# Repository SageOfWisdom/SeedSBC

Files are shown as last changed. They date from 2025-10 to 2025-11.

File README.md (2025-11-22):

# SeedSBC

## ICE40HX8K FPGA development board.
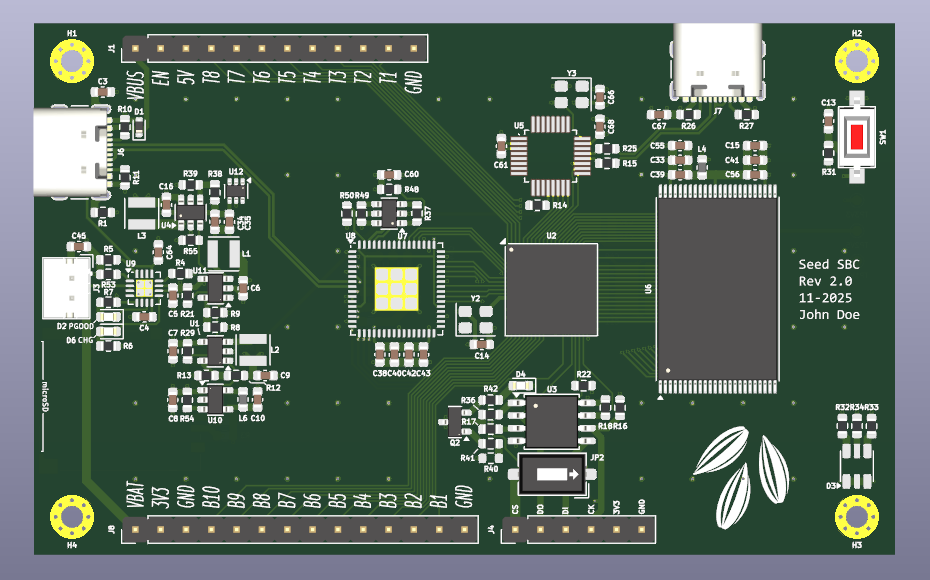
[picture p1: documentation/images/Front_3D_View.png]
Front Photo


## Latest Revision: 
* [SeedSBC rev2.0](hardware/rev2.0/)

Previous Revisions:
* [SeedSBC rev1.1](hardware/rev1.1/)
* [SeedSBC rev1.0](hardware/rev1.0/)

---

## What is it?
This is an Open Source Hardware single board computer and development board implementing the Lattice ICE40 FPGA. The board features regular I/O breakout pins, an SRAM unit, and a microSD MMC connector. The footprint is reminiscent of other "Altoids Tin" format SBCs.

## Hardware Overview
* Lattice ICE40HX8K FPGA in 121-Ball caBGA package

    * 7,680 - Logic Cells (LUT + Flip-Flop)
    * 32 - RAM4K Memory Blocks
    * 128k - RAM4K RAM bits
    * 2 - PLLs
    * 106 - Programmable I/O Pins
    * 13 - Differential Input Pairs
* SRAM Memory
    * 
* USB-C connection
    * 
* Non-Volatile Memory
    * asdf 
        * asdf
    * MicroSD socket
        * 4bit SD interface (CK, CMD, DAT0-3)
* Power supply
    * Battery charger (100mA), with LED charge indicators
    * Li-Ion battery connector
* 48MHz onboard oscillator
* Accessible 0.1" 2-wire SPI NVM programming breakout
* User I/O
    * 1x Button 
    * 1x RGB LED
    * 18x I/O on 0.1" headers
* Board Format
    * Dimensions: 86.36mm x 53.34mm (3.4" x 2.1")
    * 4x 2.2mm plated mounting holes
---

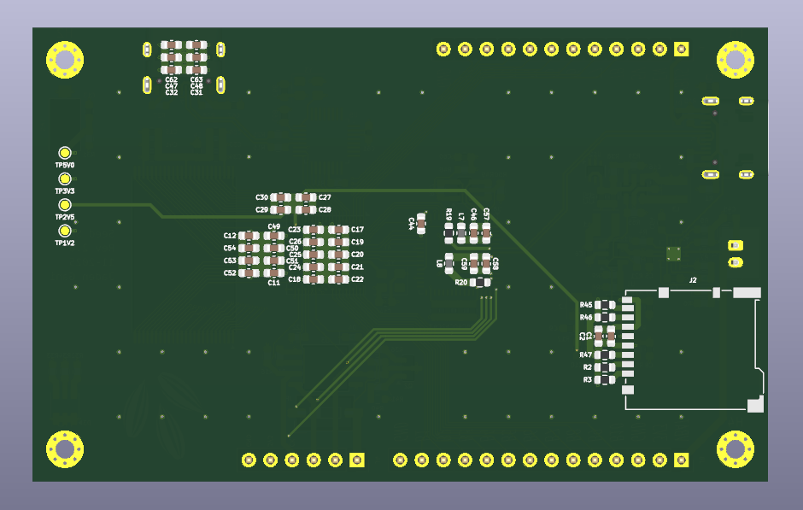
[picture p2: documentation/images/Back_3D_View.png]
Back Photo


## Example code
Example code for Verilog, And RiscV AVR can be found here:

* [ToDo]()

## Licence

 * None

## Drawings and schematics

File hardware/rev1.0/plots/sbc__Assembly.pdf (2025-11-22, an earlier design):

1 | 2 | 3 | 4 | 5 | 6

A

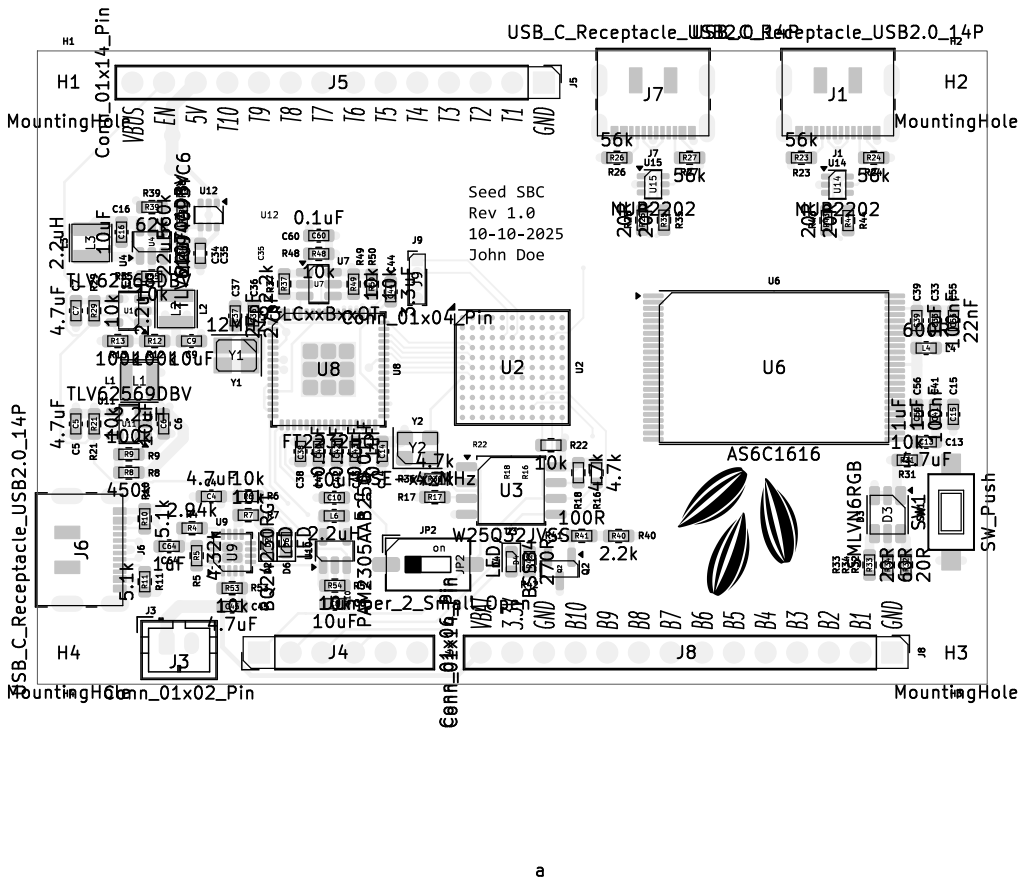
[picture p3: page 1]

Id: /1 Title: File: sbc.kicad_pcb Sheet: Black And White TOP

1 | 2 | 3 | 4 | 5 | 6

A

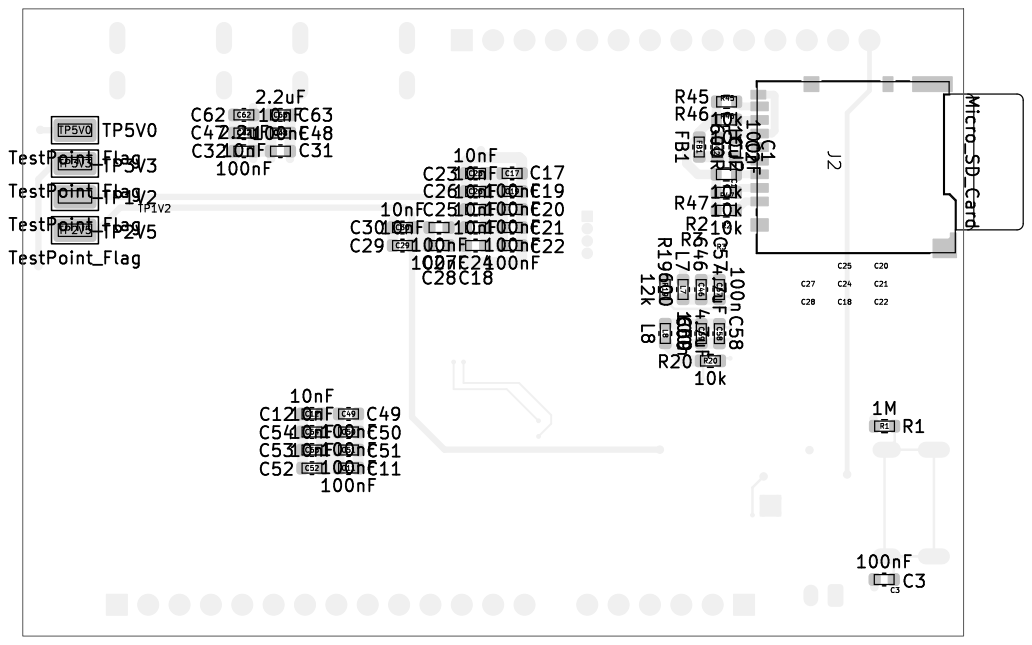
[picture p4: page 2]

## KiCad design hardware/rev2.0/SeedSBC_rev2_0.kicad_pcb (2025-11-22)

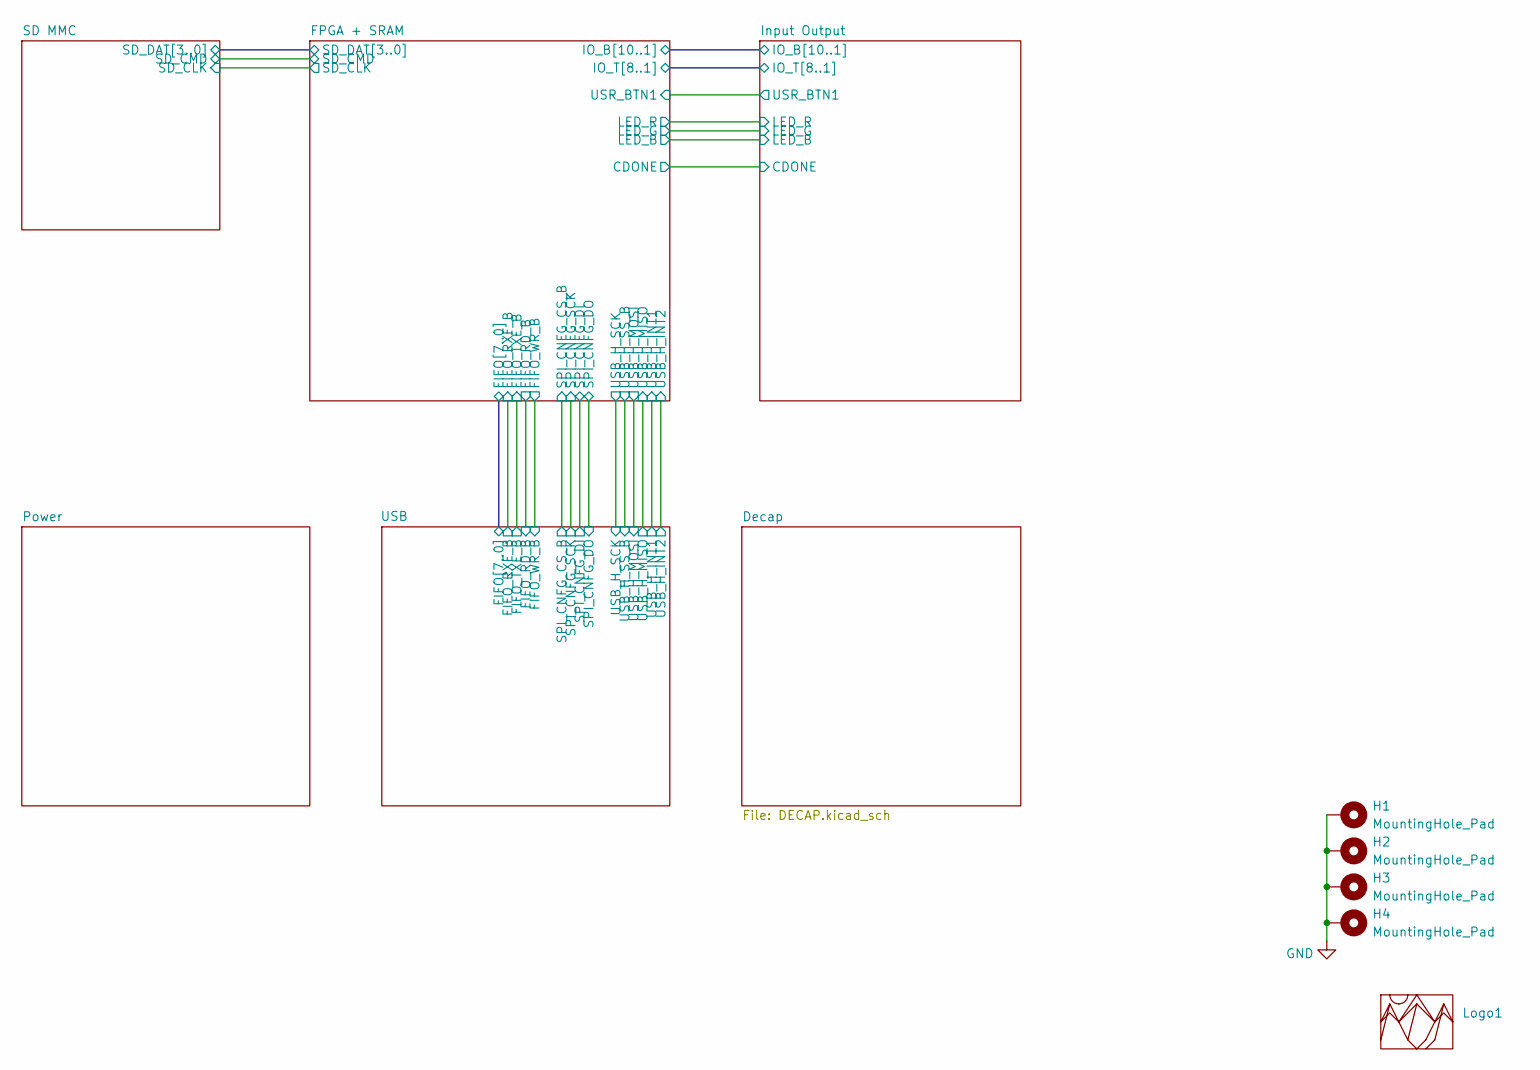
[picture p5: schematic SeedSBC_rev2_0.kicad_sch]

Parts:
H1, H2, H3, H4: MountingHole_Pad; MountingHole_2.2mm_M2_Pad_Via
Logo1: seeds

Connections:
GND: H1.1, H2.1, H3.1, H4.1; also elsewhere on the board

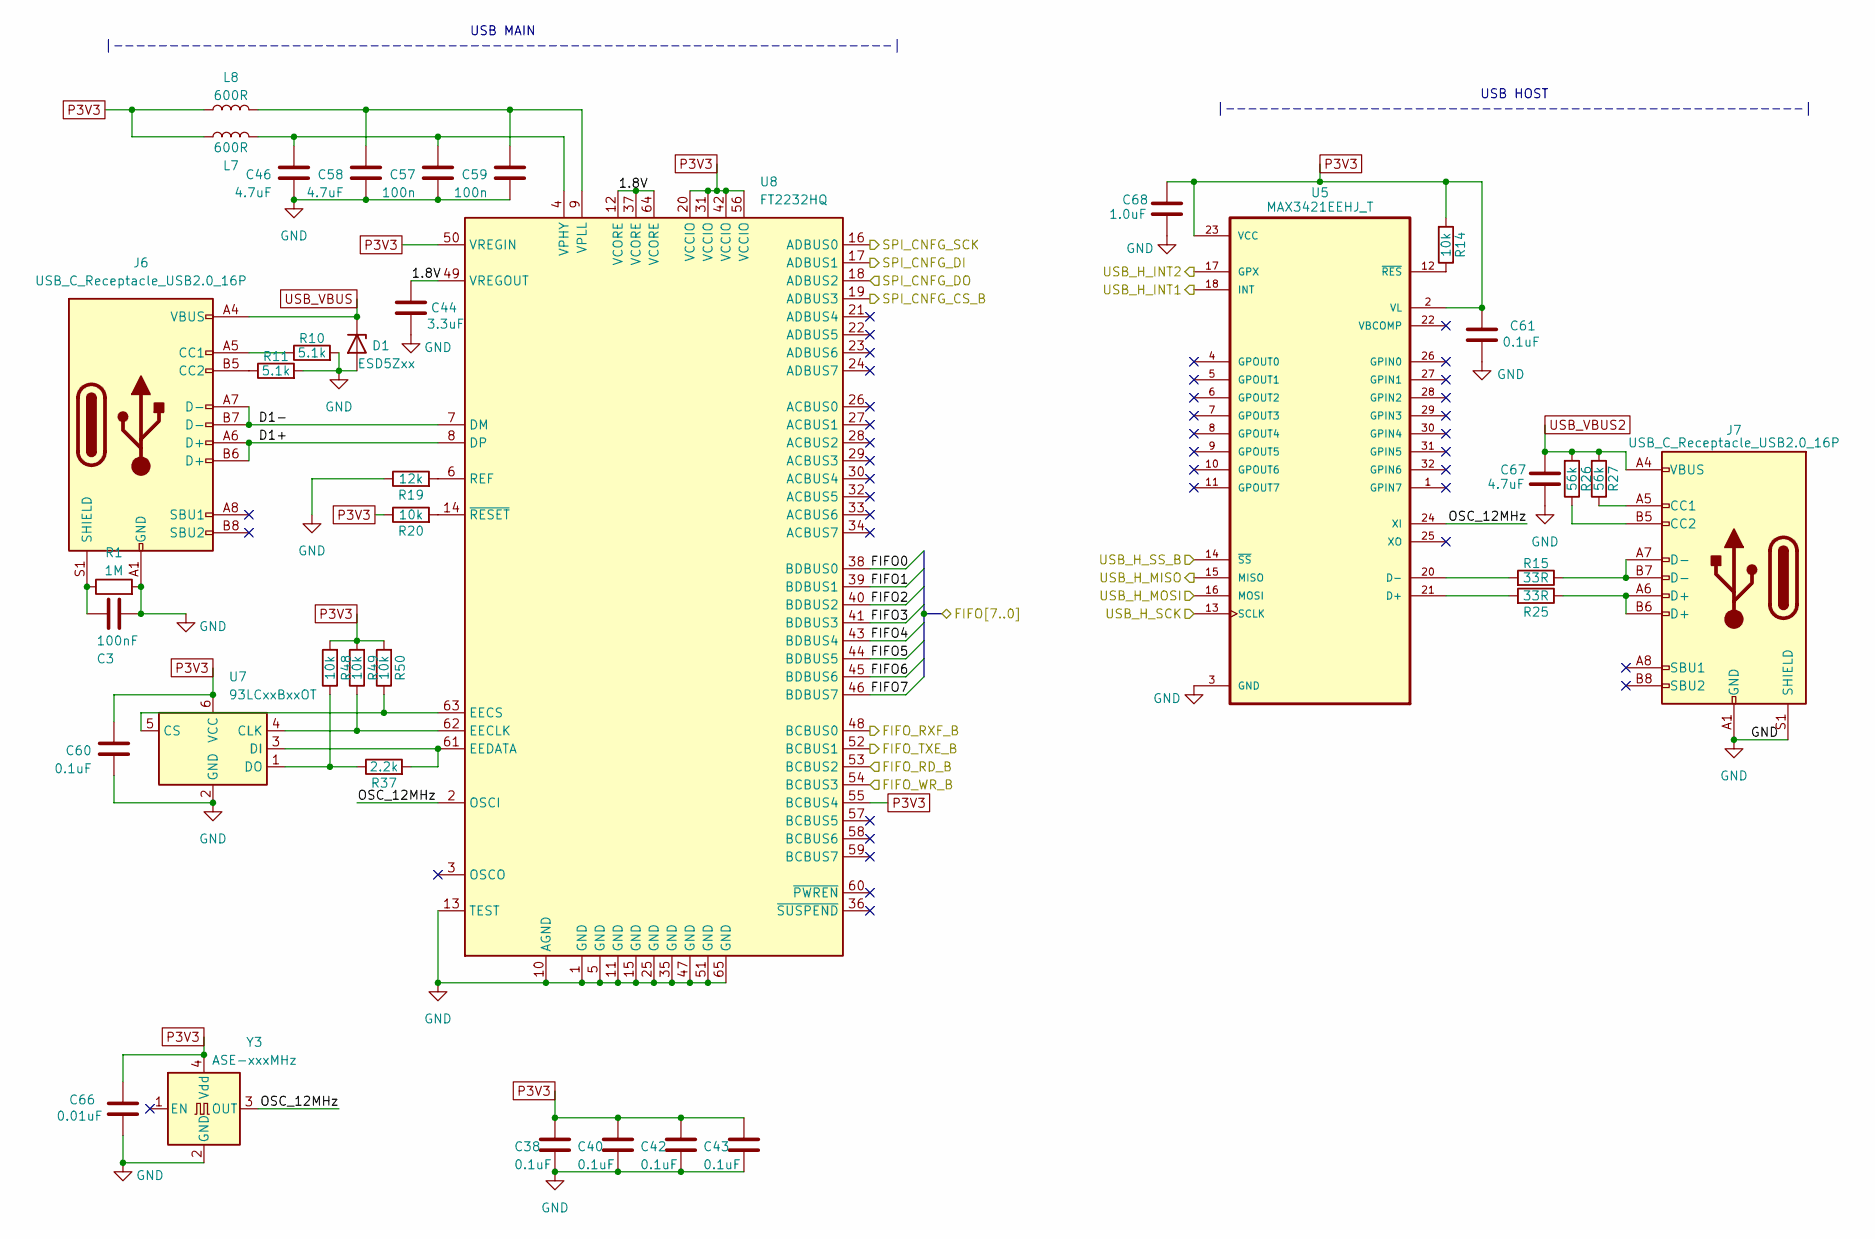
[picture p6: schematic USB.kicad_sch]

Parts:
C3: 100nF; C_0603_1608Metric
C38, C40, C42, C43, C60, C61: 0.1uF; C_0603_1608Metric
C44: 3.3uF; C_0603_1608Metric
C46, C58, C67: 4.7uF; C_0603_1608Metric
C57, C59: 100n; C_0603_1608Metric
C66: 0.01uF; C_0603_1608Metric
C68: 1.0uF; C_0603_1608Metric
D1: ESD5Zxx; D_SOD-523
J6, J7: USB_C_Receptacle_USB2.0_16P; USB_C_Receptacle_GCT_USB4105-xx-A_16P_TopMnt_Horizontal
L7, L8: 600R; L_0603_1608Metric
R1: 1M; R_0603_1608Metric
R10, R11: 5.1k; R_0603_1608Metric
R14, R20, R48, R49, R50: 10k; R_0603_1608Metric
R15, R25: 33R; R_0603_1608Metric
R19: 12k; R_0603_1608Metric
R26, R27: 56k; R_0603_1608Metric
R37: 2.2k; R_0603_1608Metric
U5: MAX3421EEHJ_T; QFP50P700X700X120-32N
U7: 93LCxxBxxOT; SOT-23-6
U8: FT2232HQ; QFN-64-1EP_9x9mm_P0.5mm_EP4.35x4.35mm
Y3: ASE-xxxMHz; Oscillator_SMD_Abracon_ASE-4Pin_3.2x2.5mm

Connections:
/FPGA + SRAM/FIFO0: U8.38 (BDBUS0); also elsewhere on the board
/FPGA + SRAM/FIFO1: U8.39 (BDBUS1); also elsewhere on the board
/FPGA + SRAM/FIFO2: U8.40 (BDBUS2); also elsewhere on the board
/FPGA + SRAM/FIFO3: U8.41 (BDBUS3); also elsewhere on the board
/FPGA + SRAM/FIFO4: U8.43 (BDBUS4); also elsewhere on the board
/FPGA + SRAM/FIFO5: U8.44 (BDBUS5); also elsewhere on the board
/FPGA + SRAM/FIFO6: U8.45 (BDBUS6); also elsewhere on the board
/FPGA + SRAM/FIFO7: U8.46 (BDBUS7); also elsewhere on the board
/FPGA + SRAM/FIFO_RD_B: U8.53 (BCBUS2); also elsewhere on the board
/FPGA + SRAM/FIFO_RXF_B: U8.48 (BCBUS0); also elsewhere on the board
/FPGA + SRAM/FIFO_TXE_B: U8.52 (BCBUS1); also elsewhere on the board
/FPGA + SRAM/FIFO_WR_B: U8.54 (BCBUS3); also elsewhere on the board
/FPGA + SRAM/FPGA/SPI_CNFG_DI: U8.17 (ADBUS1); also elsewhere on the board
/FPGA + SRAM/FPGA/SPI_CNFG_DO: U8.18 (ADBUS2); also elsewhere on the board
/FPGA + SRAM/FPGA/SPI_CNFG_SCK: U8.16 (ADBUS0); also elsewhere on the board
/FPGA + SRAM/SPI_CNFG_CS_B: U8.19 (ADBUS3); also elsewhere on the board
/FPGA + SRAM/USB_H_INT1: U5.18 (INT); also elsewhere on the board
/FPGA + SRAM/USB_H_INT2: U5.17 (GPX); also elsewhere on the board
/FPGA + SRAM/USB_H_MISO: U5.15 (MISO); also elsewhere on the board
/FPGA + SRAM/USB_H_MOSI: U5.16 (MOSI); also elsewhere on the board
/FPGA + SRAM/USB_H_SCK: U5.13 (SCLK); also elsewhere on the board
/FPGA + SRAM/USB_H_SS_B: U5.14 (~SS); also elsewhere on the board
/USB/1.8V: C44.1, U8.12 (VCORE), U8.37 (VCORE), U8.49 (VREGOUT), U8.64 (VCORE)
/USB/D1+: J6.A6 (D+), J6.B6 (D+), U8.8 (DP)
/USB/D1-: J6.A7 (D-), J6.B7 (D-), U8.7 (DM)
/USB/OSC_12MHz: U5.24 (XI), U8.2 (OSCI), Y3.3 (OUT)
GND: C3.2, C38.2, C40.2, C42.2, C43.2, C44.2, C46.2, C57.2, C58.2, C59.2, C60.2, C61.2, C66.2, C67.2, C68.2, D1.2 (A), J6.A1 (GND), J6.A12 (GND), J6.B1 (GND), J6.B12 (GND), J7.A1 (GND), J7.A12 (GND), J7.B1 (GND), J7.B12 (GND), J7.S1 (SHIELD), R1.2, R10.2, R11.2, R19.1, U5.3 (GND), U5.19 (GND), U7.2 (GND), U8.1 (GND), U8.5 (GND), U8.10 (AGND), U8.11 (GND), U8.13 (TEST), U8.15 (GND), U8.25 (GND), U8.35 (GND), U8.47 (GND), U8.51 (GND), U8.65 (GND), Y3.2 (GND); also elsewhere on the board
unnamed: J6.A5 (CC1), R10.1
unnamed: J6.B5 (CC2), R11.1
unnamed: C3.1, J6.S1 (SHIELD), R1.1
unnamed: J7.A5 (CC1), R27.1
unnamed: J7.B5 (CC2), R26.1
unnamed: J7.A6 (D+), J7.B6 (D+), R25.1
unnamed: J7.A7 (D-), J7.B7 (D-), R15.1
unnamed: R25.2, U5.21 (D+)
unnamed: R15.2, U5.20 (D-)
unnamed: R14.1, U5.12 (~RES)
unnamed: R49.1, U7.4 (CLK), U8.62 (EECLK)
unnamed: R50.1, U7.5 (CS), U8.63 (EECS)
unnamed: R37.2, U7.3 (DI), U8.61 (EEDATA)
unnamed: R37.1, R48.1, U7.1 (DO)
unnamed: R19.2, U8.6 (REF)
unnamed: C46.1, C57.1, L7.2, U8.4 (VPHY)
unnamed: C58.1, C59.1, L8.2, U8.9 (VPLL)
unnamed: R20.2, U8.14 (~RESET)
P3V3: C38.1, C40.1, C42.1, C43.1, C60.1, C61.1, C66.1, C68.1, L7.1, L8.1, R14.2, R20.1, R48.2, R49.2, R50.2, U5.2 (VL), U5.23 (VCC), U7.6 (VCC), U8.20 (VCCIO), U8.31 (VCCIO), U8.42 (VCCIO), U8.50 (VREGIN), U8.55 (BCBUS4), U8.56 (VCCIO), Y3.4 (Vdd); also elsewhere on the board
USB_VBUS: D1.1 (K), J6.A4 (VBUS), J6.A9 (VBUS), J6.B4 (VBUS), J6.B9 (VBUS); also elsewhere on the board
USB_VBUS2: C67.1, J7.A4 (VBUS), J7.A9 (VBUS), J7.B4 (VBUS), J7.B9 (VBUS), R26.2, R27.2; also elsewhere on the board

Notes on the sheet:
USB HOST |----------------------------------------------------|
USB MAIN |----------------------------------------------------------------------|

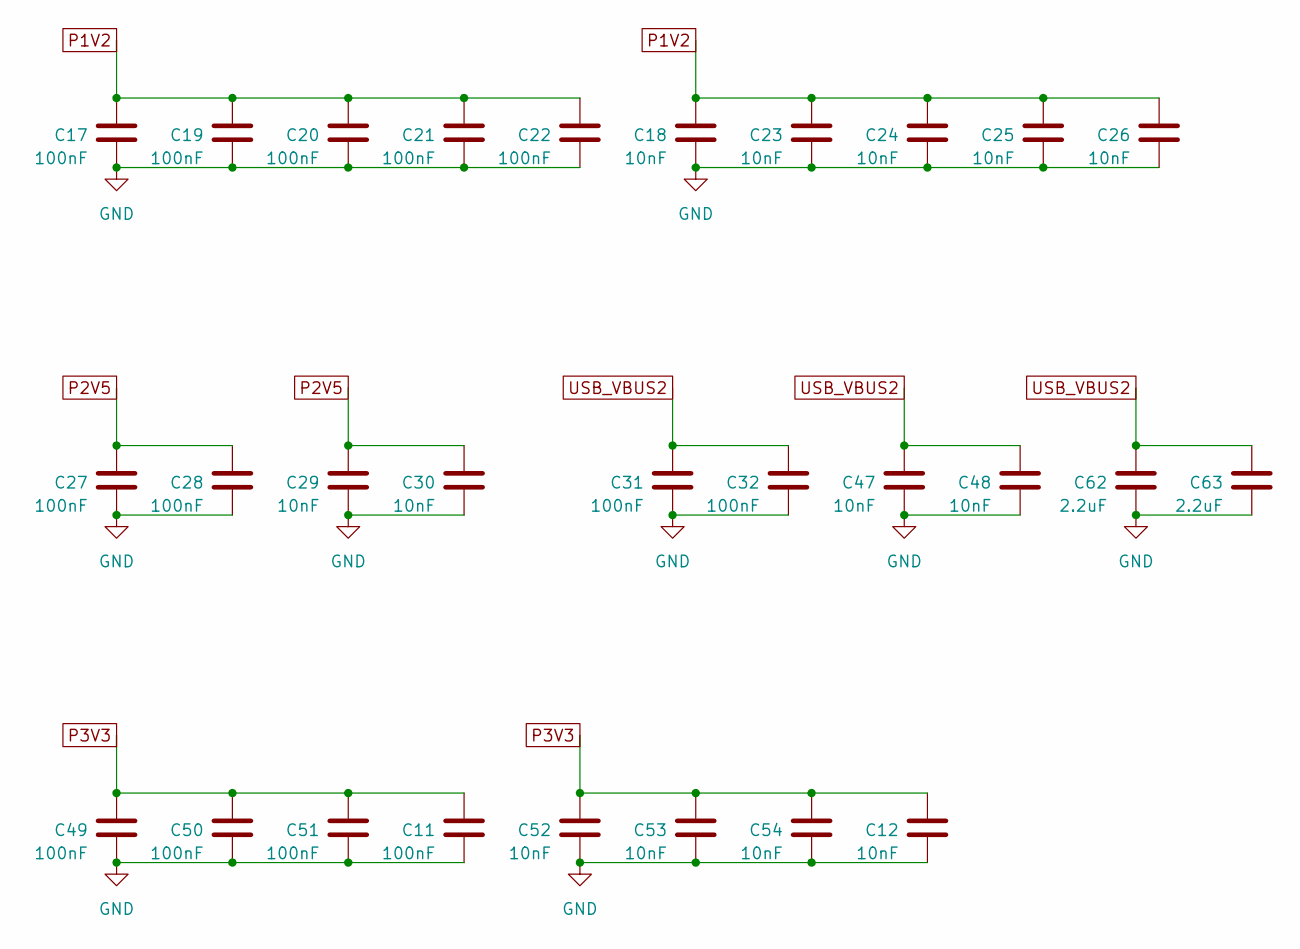
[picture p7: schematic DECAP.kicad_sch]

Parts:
C11, C17, C19, C20, C21, C22, C27, C28, C31, C32, C49, C50, C51: 100nF; C_0603_1608Metric
C12, C18, C23, C24, C25, C26, C29, C30, C47, C48, C52, C53, C54: 10nF; C_0603_1608Metric
C62, C63: 2.2uF; C_0603_1608Metric

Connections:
GND: C11.2, C12.2, C17.2, C18.2, C19.2, C20.2, C21.2, C22.2, C23.2, C24.2, C25.2, C26.2, C27.2, C28.2, C29.2, C30.2, C31.2, C32.2, C47.2, C48.2, C49.2, C50.2, C51.2, C52.2, C53.2, C54.2, C62.2, C63.2; also elsewhere on the board
P1V2: C17.1, C18.1, C19.1, C20.1, C21.1, C22.1, C23.1, C24.1, C25.1, C26.1; also elsewhere on the board
P2V5: C27.1, C28.1, C29.1, C30.1; also elsewhere on the board
P3V3: C11.1, C12.1, C49.1, C50.1, C51.1, C52.1, C53.1, C54.1; also elsewhere on the board
USB_VBUS2: C31.1, C32.1, C47.1, C48.1, C62.1, C63.1; also elsewhere on the board

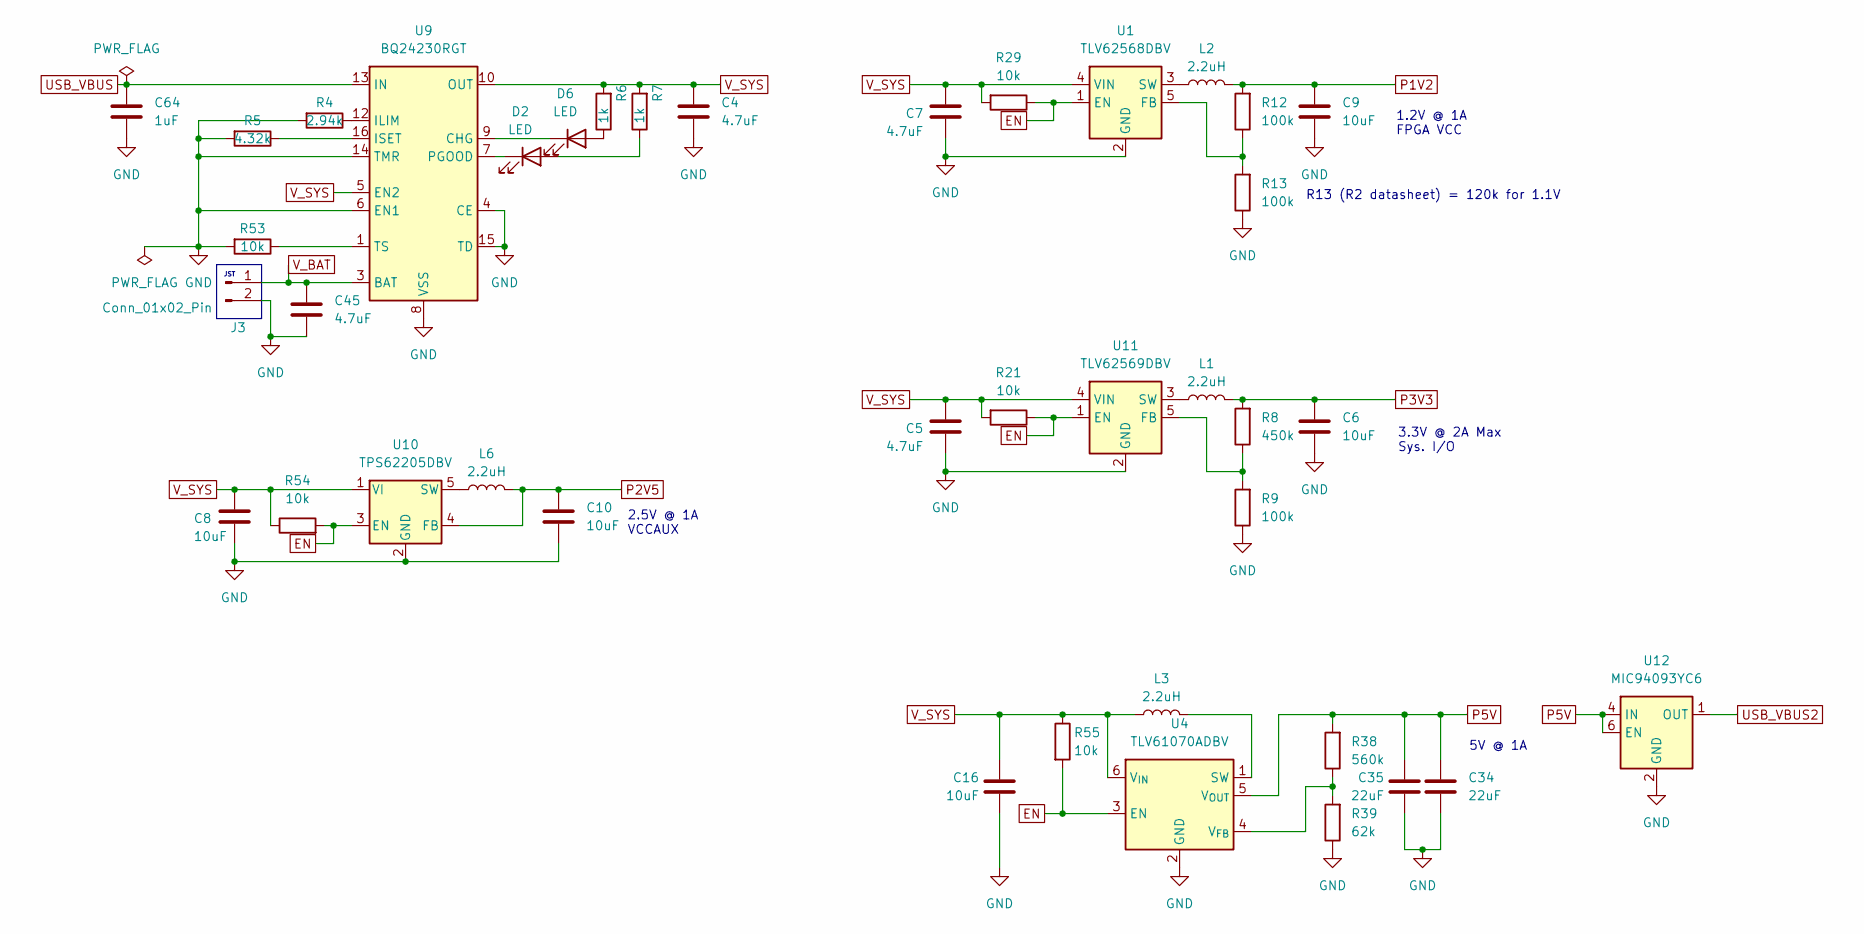
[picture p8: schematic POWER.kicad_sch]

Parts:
C4, C5, C7, C45: 4.7uF; C_0603_1608Metric
C6, C8, C9, C10, C16: 10uF; C_0603_1608Metric
C34, C35: 22uF; C_0603_1608Metric
C64: 1uF; C_0603_1608Metric
D2, D6: LED; LED_0603_1608Metric
J3: Conn_01x02_Pin; JST_PH_B2B-PH-K_1x02_P2.00mm_Vertical
L1, L2, L3: 2.2uH; L_Neosid_SMS-ME3010
L6: 2.2uH; L_0603_1608Metric
R4: 2.94k; R_0603_1608Metric
R5: 4.32k; R_0603_1608Metric
R6, R7: 1k; R_0603_1608Metric
R8: 450k; R_0603_1608Metric
R9, R12, R13: 100k; R_0603_1608Metric
R21, R29, R53, R54, R55: 10k; R_0603_1608Metric
R38: 560k; R_0603_1608Metric
R39: 62k; R_0603_1608Metric
U1: TLV62568DBV; SOT-23-5
U4: TLV61070ADBV; SOT-23-6
U9: BQ24230RGT; VQFN-16-1EP_3x3mm_P0.5mm_EP1.68x1.68mm_ThermalVias
U10: TPS62205DBV; SOT-23-5
U11: TLV62569DBV; SOT-23-5
U12: MIC94093YC6; SOT-363_SC-70-6

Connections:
EN: R21.1, R29.1, R54.2, R55.2, U1.1 (EN), U4.3 (EN), U10.3 (EN), U11.1 (EN); also elsewhere on the board
GND: C4.2, C5.2, C6.2, C7.2, C8.2, C9.2, C10.2, C16.2, C34.2, C35.2, C45.2, C64.2, J3.2, R4.2, R5.2, R9.1, R13.1, R39.1, R53.2, U1.2 (GND), U4.2 (GND), U9.4 (CE), U9.6 (EN1), U9.8 (VSS), U9.14 (TMR), U9.15 (TD), U9.17 (VSS), U10.2 (GND), U11.2 (GND), U12.2 (GND), U12.5 (GND); also elsewhere on the board
unnamed: D2.2 (A), R7.1
unnamed: D2.1 (K), U9.7 (PGOOD)
unnamed: D6.2 (A), R6.1
unnamed: D6.1 (K), U9.9 (CHG)
unnamed: R12.1, R13.2, U1.5 (FB)
unnamed: L2.1, U1.3 (SW)
unnamed: L3.2, U4.1 (SW)
unnamed: R38.1, R39.2, U4.4 (V_{FB})
unnamed: R4.1, U9.12 (ILIM)
unnamed: R5.1, U9.16 (ISET)
unnamed: R53.1, U9.1 (TS)
unnamed: L6.1, U10.5 (SW)
unnamed: R8.1, R9.2, U11.5 (FB)
unnamed: L1.1, U11.3 (SW)
P1V2: C9.1, L2.2, R12.2; also elsewhere on the board
P2V5: C10.1, L6.2, U10.4 (FB); also elsewhere on the board
P3V3: C6.1, L1.2, R8.2; also elsewhere on the board
P5V: C34.1, C35.1, R38.2, U4.5 (V_{OUT}), U12.4 (IN), U12.6 (EN)
USB_VBUS: C64.1, U9.13 (IN); also elsewhere on the board
USB_VBUS2: U12.1 (OUT); also elsewhere on the board
V_BAT: C45.1, J3.1, U9.2 (BAT), U9.3 (BAT); also elsewhere on the board
V_SYS: C4.1, C5.1, C7.1, C8.1, C16.1, L3.1, R6.2, R7.2, R21.2, R29.2, R54.1, R55.1, U1.4 (VIN), U4.6 (V_{IN}), U9.5 (EN2), U9.10 (OUT), U9.11 (OUT), U10.1 (VI), U11.4 (VIN)

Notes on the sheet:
5V @ 1A
2.5V @ 1A VCCAUX
3.3V @ 2A Max Sys. I/O
R13 (R2 datasheet) = 120k for 1.1V
1.2V @ 1A FPGA VCC
JST

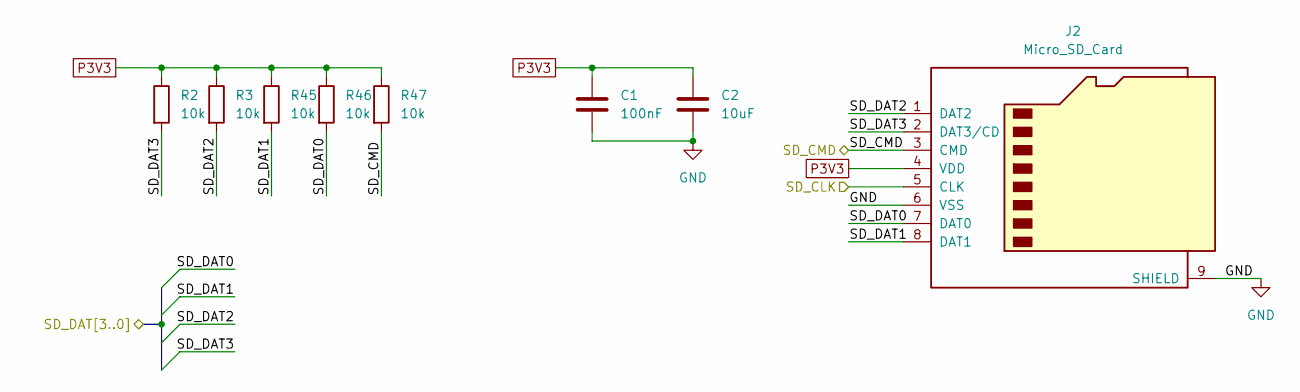
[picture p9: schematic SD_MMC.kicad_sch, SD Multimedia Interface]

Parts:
C1: 100nF; C_0603_1608Metric
C2: 10uF; C_0603_1608Metric
J2: Micro_SD_Card; microSD_HC_Hirose_DM3BT-DSF-PEJS
R2, R3, R45, R46, R47: 10k; R_0603_1608Metric

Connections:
/FPGA + SRAM/SD_CLK: J2.5 (CLK); also elsewhere on the board
/FPGA + SRAM/SD_DAT0: J2.7 (DAT0), R46.2; also elsewhere on the board
/FPGA + SRAM/SD_DAT1: J2.8 (DAT1), R45.2; also elsewhere on the board
/FPGA + SRAM/SD_DAT2: J2.1 (DAT2), R3.2; also elsewhere on the board
/FPGA + SRAM/SD_DAT3: J2.2 (DAT3/CD), R2.2; also elsewhere on the board
/SD MMC/SD_CMD: J2.3 (CMD), R47.2; also elsewhere on the board
GND: C1.2, C2.2, J2.6 (VSS), J2.9 (SHIELD); also elsewhere on the board
P3V3: C1.1, C2.1, J2.4 (VDD), R2.1, R3.1, R45.1, R46.1, R47.1; also elsewhere on the board

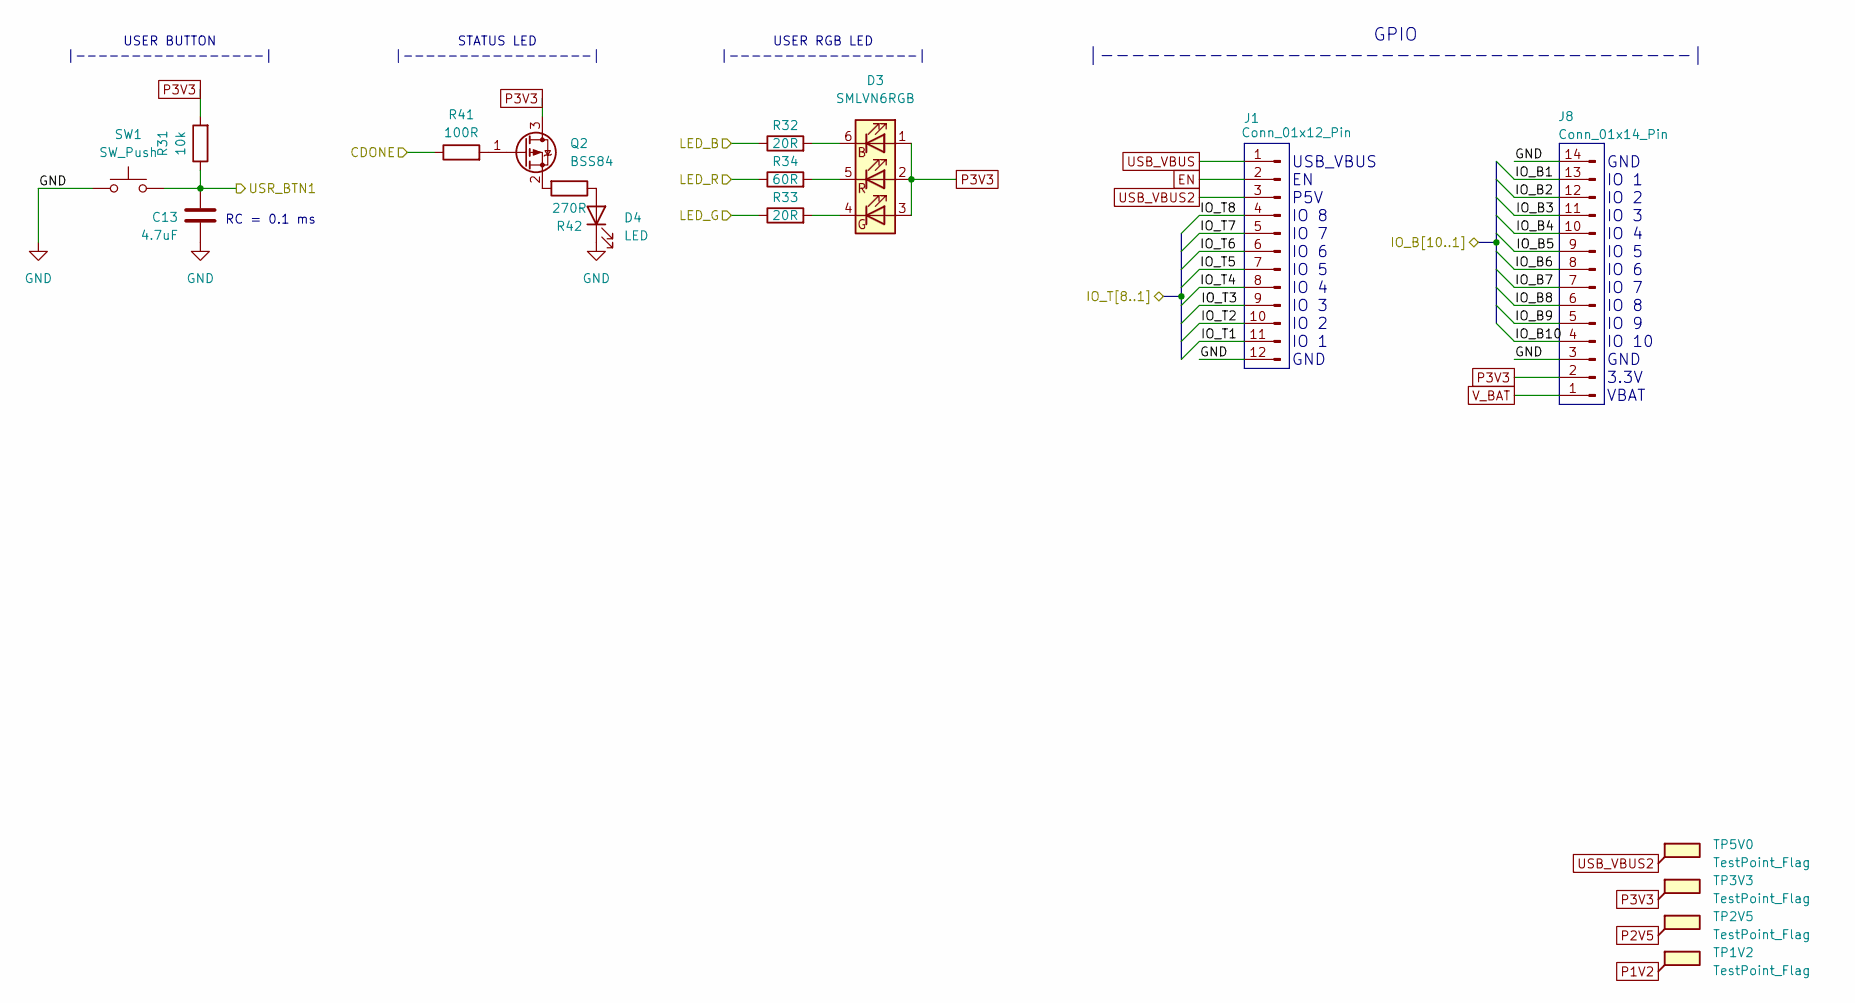
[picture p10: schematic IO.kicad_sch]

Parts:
C13: 4.7uF; C_0603_1608Metric
D3: SMLVN6RGB; LED_ROHM_SMLVN6
D4: LED; LED_0603_1608Metric
J1: Conn_01x12_Pin; PinHeader_1x12_P2.54mm_Vertical
J8: Conn_01x14_Pin; PinHeader_1x14_P2.54mm_Vertical
Q2: BSS84; SOT-23
R31: 10k; R_0603_1608Metric
R32, R33: 20R; R_0603_1608Metric
R34: 60R; R_0603_1608Metric
R41: 100R; R_0603_1608Metric
R42: 270R; R_0603_1608Metric
SW1: SW_Push; SW_SPST_CK_RS282G05A3
TP1V2, TP2V5, TP3V3, TP5V0: TestPoint_Flag; TestPoint_Pad_D1.0mm

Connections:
/FPGA + SRAM/CDONE: R41.1; also elsewhere on the board
/FPGA + SRAM/IO_B1: J8.13; also elsewhere on the board
/FPGA + SRAM/IO_B2: J8.12; also elsewhere on the board
/FPGA + SRAM/IO_B3: J8.11; also elsewhere on the board
/FPGA + SRAM/IO_B4: J8.10; also elsewhere on the board
/FPGA + SRAM/IO_B5: J8.9; also elsewhere on the board
/FPGA + SRAM/IO_B6: J8.8; also elsewhere on the board
/FPGA + SRAM/IO_B7: J8.7; also elsewhere on the board
/FPGA + SRAM/IO_B8: J8.6; also elsewhere on the board
/FPGA + SRAM/IO_B9: J8.5; also elsewhere on the board
/FPGA + SRAM/IO_B10: J8.4; also elsewhere on the board
/FPGA + SRAM/IO_T1: J1.11; also elsewhere on the board
/FPGA + SRAM/IO_T2: J1.10; also elsewhere on the board
/FPGA + SRAM/IO_T3: J1.9; also elsewhere on the board
/FPGA + SRAM/IO_T4: J1.8; also elsewhere on the board
/FPGA + SRAM/IO_T5: J1.7; also elsewhere on the board
/FPGA + SRAM/IO_T6: J1.6; also elsewhere on the board
/FPGA + SRAM/IO_T7: J1.5; also elsewhere on the board
/FPGA + SRAM/IO_T8: J1.4; also elsewhere on the board
/FPGA + SRAM/LED_B: R32.1; also elsewhere on the board
/FPGA + SRAM/LED_G: R33.1; also elsewhere on the board
/FPGA + SRAM/LED_R: R34.1; also elsewhere on the board
/FPGA + SRAM/USR_BTN1: C13.1, R31.1, SW1.2; also elsewhere on the board
EN: J1.2; also elsewhere on the board
GND: C13.2, D4.1 (K), J1.12, J8.3, J8.14, SW1.1; also elsewhere on the board
unnamed: D3.6 (BK), R32.2
unnamed: D3.4 (GK), R33.2
unnamed: D3.5 (RK), R34.2
unnamed: D4.2 (A), R42.1
unnamed: Q2.1 (G), R41.2
unnamed: Q2.2 (S), R42.2
P1V2: TP1V2.1; also elsewhere on the board
P2V5: TP2V5.1; also elsewhere on the board
P3V3: D3.1 (BA), D3.2 (RA), D3.3 (GA), J8.2, Q2.3 (D), R31.2, TP3V3.1; also elsewhere on the board
USB_VBUS: J1.1; also elsewhere on the board
USB_VBUS2: J1.3, TP5V0.1; also elsewhere on the board
V_BAT: J8.1; also elsewhere on the board

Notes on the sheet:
USER RGB LED |-----------------|
USER BUTTON |-----------------|
GPIO |--------------------------------------|
GND IO 1 IO 2 IO 3 IO 4 IO 5 IO 6 IO 7 IO 8 IO 9 IO 10 GND 3.3V VBAT
RC = 0.1 ms
USB_VBUS EN P5V IO 8 IO 7 IO 6 IO 5 IO 4 IO 3 IO 2 IO 1 GND
STATUS LED |-----------------|

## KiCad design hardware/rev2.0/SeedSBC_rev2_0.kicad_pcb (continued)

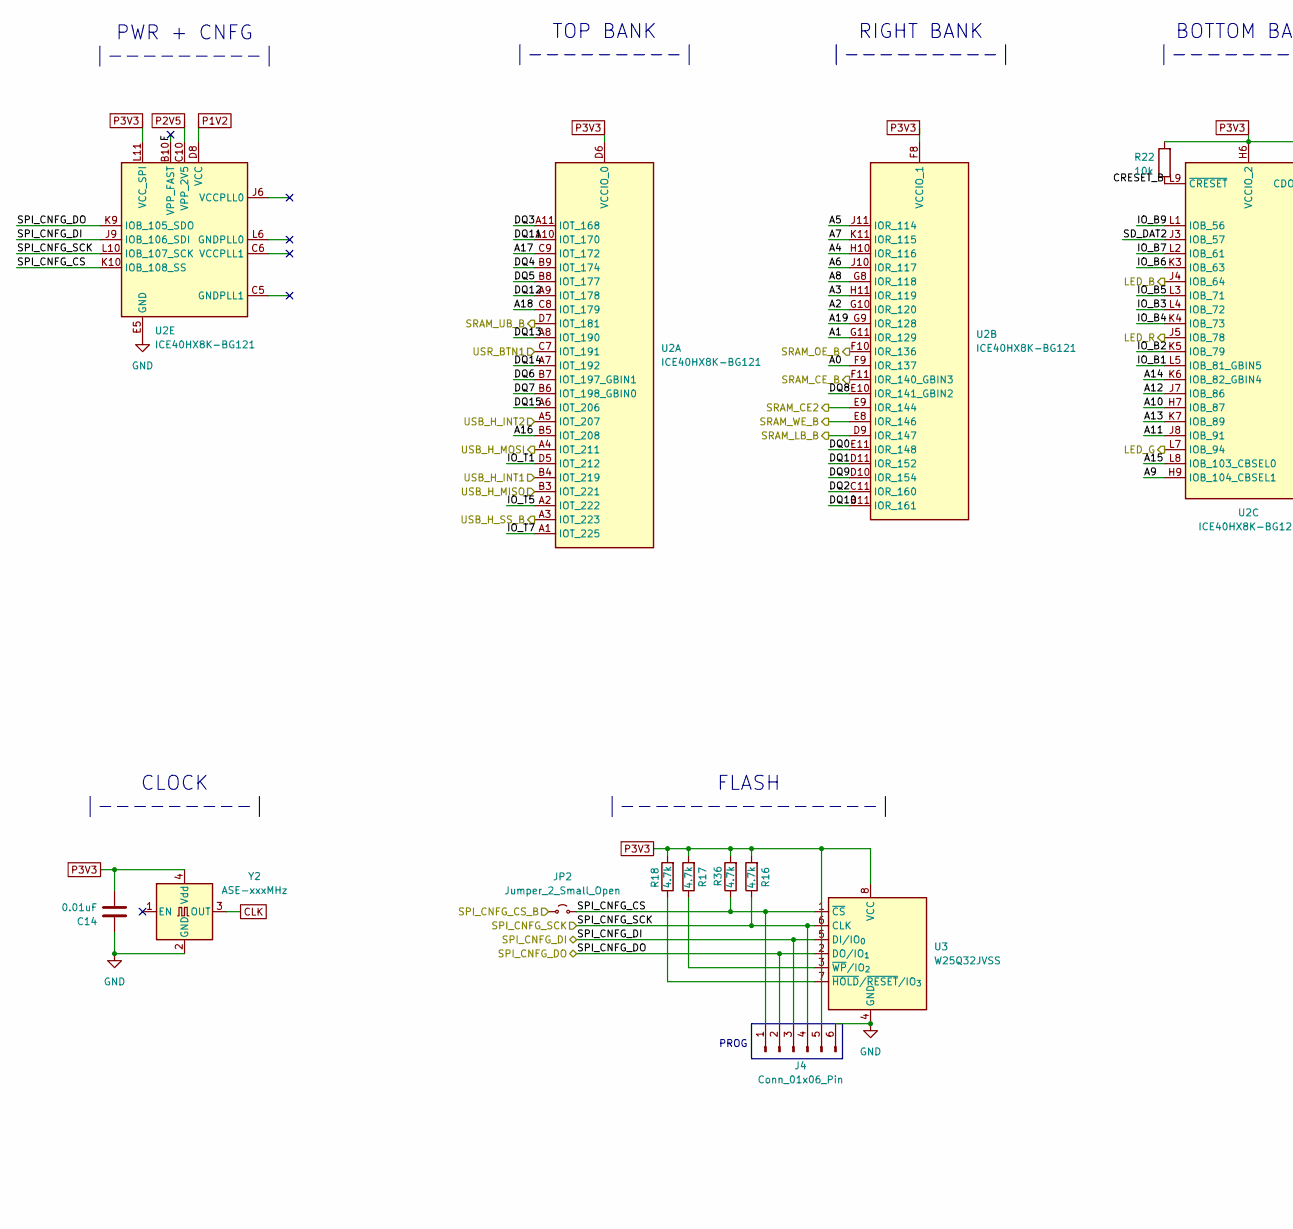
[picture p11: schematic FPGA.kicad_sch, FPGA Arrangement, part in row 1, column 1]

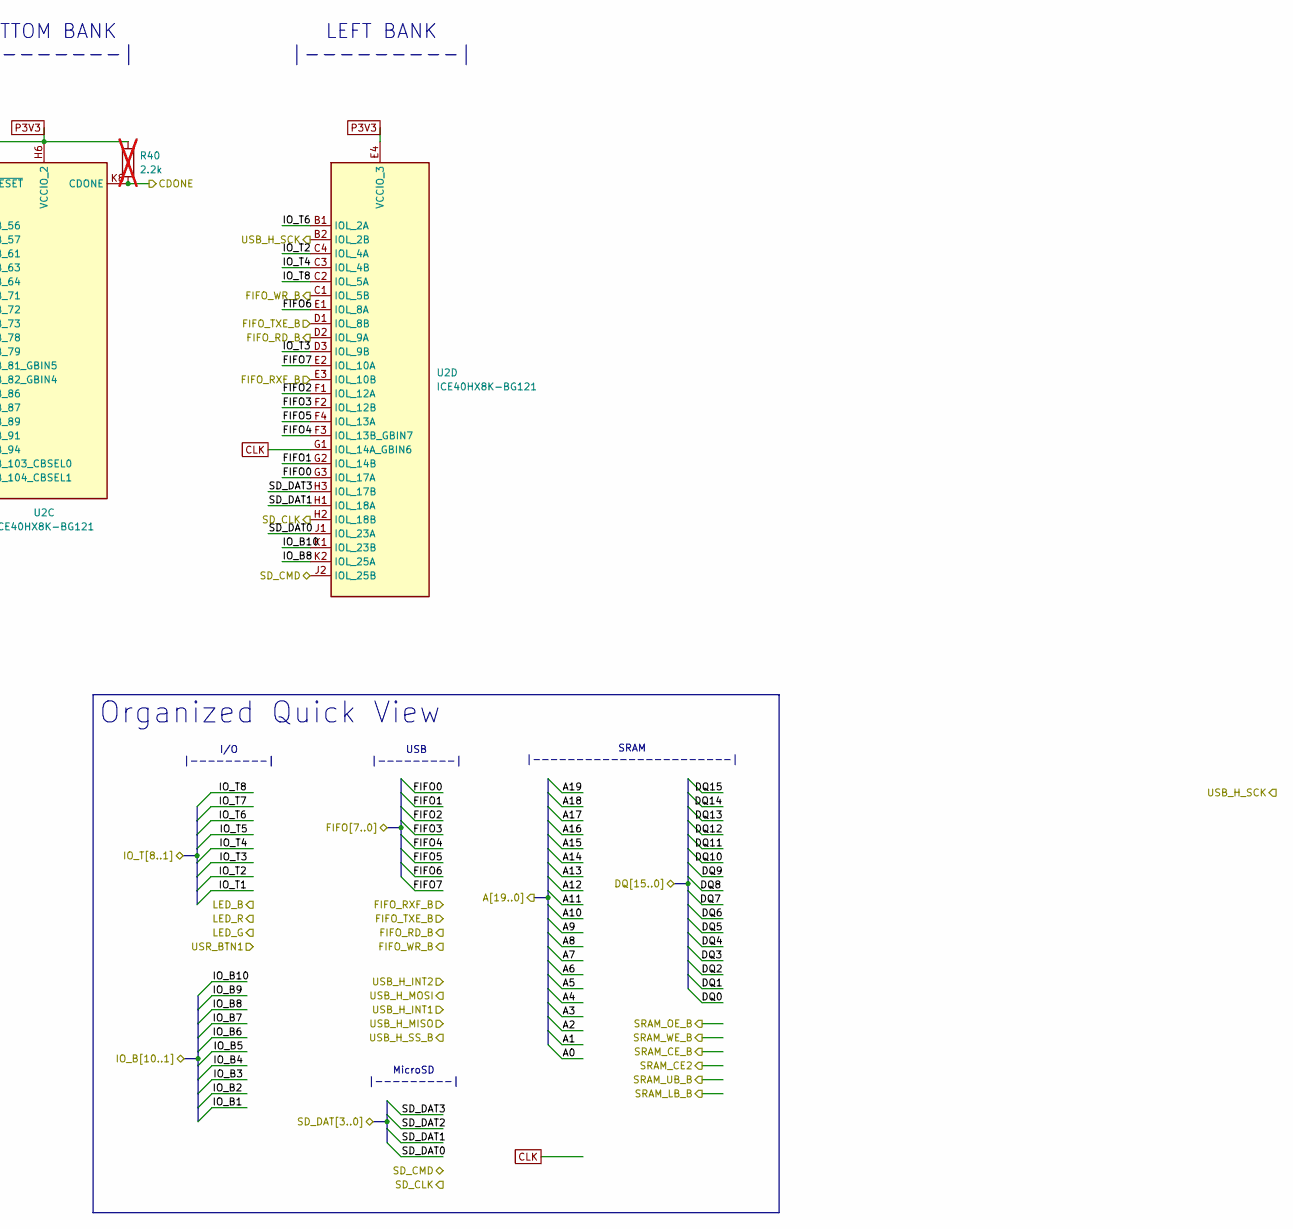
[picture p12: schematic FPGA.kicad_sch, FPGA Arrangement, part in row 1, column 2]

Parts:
C14: 0.01uF; C_0603_1608Metric
J4: Conn_01x06_Pin; PinHeader_1x06_P2.54mm_Vertical
JP2: Jumper_2_Small_Open; SW_DIP_SPSTx01_Slide_6.7x4.1mm_W6.73mm_P2.54mm_LowProfile_J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
R16, R17, R18, R36: 4.7k; R_0603_1608Metric
R22: 10k; R_0603_1608Metric
R40: 2.2k; R_0603_1608Metric; not fitted
U2: ICE40HX8K-BG121; BGA-121_9.0x9.0mm_Layout11x11_P0.8mm_Ball0.4mm_Pad0.35mm_NS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
U3: W25Q32JVSS; SOIC-8_5.3x5.3mm_P1.27mm
Y2: ASE-xxxMHz; Oscillator_SMD_Abracon_ASE-4Pin_3.2x2.5mm

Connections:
/FPGA + SRAM/CDONE: R40.1, U2.K8 (CDONE); also elsewhere on the board
/FPGA + SRAM/FIFO0: U2.G3 (IOL_17A); also elsewhere on the board
/FPGA + SRAM/FIFO1: U2.G2 (IOL_14B); also elsewhere on the board
/FPGA + SRAM/FIFO2: U2.F1 (IOL_12A); also elsewhere on the board
/FPGA + SRAM/FIFO3: U2.F2 (IOL_12B); also elsewhere on the board
/FPGA + SRAM/FIFO4: U2.F3 (IOL_13B_GBIN7); also elsewhere on the board
/FPGA + SRAM/FIFO5: U2.F4 (IOL_13A); also elsewhere on the board
/FPGA + SRAM/FIFO6: U2.E1 (IOL_8A); also elsewhere on the board
/FPGA + SRAM/FIFO7: U2.E2 (IOL_10A); also elsewhere on the board
/FPGA + SRAM/FIFO_RD_B: U2.D2 (IOL_9A); also elsewhere on the board
/FPGA + SRAM/FIFO_RXF_B: U2.E3 (IOL_10B); also elsewhere on the board
/FPGA + SRAM/FIFO_TXE_B: U2.D1 (IOL_8B); also elsewhere on the board
/FPGA + SRAM/FIFO_WR_B: U2.C1 (IOL_5B); also elsewhere on the board
/FPGA + SRAM/FPGA/A0: U2.F9 (IOR_137); also elsewhere on the board
/FPGA + SRAM/FPGA/A1: U2.G11 (IOR_129); also elsewhere on the board
/FPGA + SRAM/FPGA/A2: U2.G10 (IOR_120); also elsewhere on the board
/FPGA + SRAM/FPGA/A3: U2.H11 (IOR_119); also elsewhere on the board
/FPGA + SRAM/FPGA/A4: U2.H10 (IOR_116); also elsewhere on the board
/FPGA + SRAM/FPGA/A5: U2.J11 (IOR_114); also elsewhere on the board
/FPGA + SRAM/FPGA/A6: U2.J10 (IOR_117); also elsewhere on the board
/FPGA + SRAM/FPGA/A7: U2.K11 (IOR_115); also elsewhere on the board
/FPGA + SRAM/FPGA/A8: U2.G8 (IOR_118); also elsewhere on the board
/FPGA + SRAM/FPGA/A9: U2.H9 (IOB_104_CBSEL1); also elsewhere on the board
/FPGA + SRAM/FPGA/A10: U2.H7 (IOB_87); also elsewhere on the board
/FPGA + SRAM/FPGA/A11: U2.J8 (IOB_91); also elsewhere on the board
/FPGA + SRAM/FPGA/A12: U2.J7 (IOB_86); also elsewhere on the board
/FPGA + SRAM/FPGA/A13: U2.K7 (IOB_89); also elsewhere on the board
/FPGA + SRAM/FPGA/A14: U2.K6 (IOB_82_GBIN4); also elsewhere on the board
/FPGA + SRAM/FPGA/A15: U2.L8 (IOB_103_CBSEL0); also elsewhere on the board
/FPGA + SRAM/FPGA/A16: U2.B5 (IOT_208); also elsewhere on the board
/FPGA + SRAM/FPGA/A17: U2.C9 (IOT_172); also elsewhere on the board
/FPGA + SRAM/FPGA/A18: U2.C8 (IOT_179); also elsewhere on the board
/FPGA + SRAM/FPGA/A19: U2.G9 (IOR_128); also elsewhere on the board
/FPGA + SRAM/FPGA/CRESET_B: R22.1, U2.L9 (~CRESET)
/FPGA + SRAM/FPGA/DQ0: U2.E11 (IOR_148); also elsewhere on the board
/FPGA + SRAM/FPGA/DQ1: U2.D11 (IOR_152); also elsewhere on the board
/FPGA + SRAM/FPGA/DQ2: U2.C11 (IOR_160); also elsewhere on the board
/FPGA + SRAM/FPGA/DQ3: U2.A11 (IOT_168); also elsewhere on the board
/FPGA + SRAM/FPGA/DQ4: U2.B9 (IOT_174); also elsewhere on the board
/FPGA + SRAM/FPGA/DQ5: U2.B8 (IOT_177); also elsewhere on the board
/FPGA + SRAM/FPGA/DQ6: U2.B7 (IOT_197_GBIN1); also elsewhere on the board
/FPGA + SRAM/FPGA/DQ7: U2.B6 (IOT_198_GBIN0); also elsewhere on the board
/FPGA + SRAM/FPGA/DQ8: U2.E10 (IOR_141_GBIN2); also elsewhere on the board
/FPGA + SRAM/FPGA/DQ9: U2.D10 (IOR_154); also elsewhere on the board
/FPGA + SRAM/FPGA/DQ10: U2.B11 (IOR_161); also elsewhere on the board
/FPGA + SRAM/FPGA/DQ11: U2.A10 (IOT_170); also elsewhere on the board
/FPGA + SRAM/FPGA/DQ12: U2.A9 (IOT_178); also elsewhere on the board
/FPGA + SRAM/FPGA/DQ13: U2.A8 (IOT_190); also elsewhere on the board
/FPGA + SRAM/FPGA/DQ14: U2.A7 (IOT_192); also elsewhere on the board
/FPGA + SRAM/FPGA/DQ15: U2.A6 (IOT_206); also elsewhere on the board
/FPGA + SRAM/FPGA/F: U2.B10 (VPP_FAST)
/FPGA + SRAM/FPGA/SPI_CNFG_CS: J4.1, JP2.2 (B), R36.1, U2.K10 (IOB_108_SS), U3.1 (~CS)
/FPGA + SRAM/FPGA/SPI_CNFG_DI: J4.3, U2.J9 (IOB_106_SDI), U3.5 (DI/IO_{0}); also elsewhere on the board
/FPGA + SRAM/FPGA/SPI_CNFG_DO: J4.2, U2.K9 (IOB_105_SDO), U3.2 (DO/IO_{1}); also elsewhere on the board
/FPGA + SRAM/FPGA/SPI_CNFG_SCK: J4.4, R16.1, U2.L10 (IOB_107_SCK), U3.6 (CLK); also elsewhere on the board
/FPGA + SRAM/FPGA/SRAM_CE2: U2.E9 (IOR_144); also elsewhere on the board
/FPGA + SRAM/FPGA/SRAM_CE_B: U2.F11 (IOR_140_GBIN3); also elsewhere on the board
/FPGA + SRAM/FPGA/SRAM_LB_B: U2.D9 (IOR_147); also elsewhere on the board
/FPGA + SRAM/FPGA/SRAM_OE_B: U2.F10 (IOR_136); also elsewhere on the board
/FPGA + SRAM/FPGA/SRAM_UB_B: U2.D7 (IOT_181); also elsewhere on the board
/FPGA + SRAM/FPGA/SRAM_WE_B: U2.E8 (IOR_146); also elsewhere on the board
/FPGA + SRAM/IO_B1: U2.L5 (IOB_81_GBIN5); also elsewhere on the board
/FPGA + SRAM/IO_B2: U2.K5 (IOB_79); also elsewhere on the board
/FPGA + SRAM/IO_B3: U2.L4 (IOB_72); also elsewhere on the board
/FPGA + SRAM/IO_B4: U2.K4 (IOB_73); also elsewhere on the board
/FPGA + SRAM/IO_B5: U2.L3 (IOB_71); also elsewhere on the board
/FPGA + SRAM/IO_B6: U2.K3 (IOB_63); also elsewhere on the board
/FPGA + SRAM/IO_B7: U2.L2 (IOB_61); also elsewhere on the board
/FPGA + SRAM/IO_B8: U2.K2 (IOL_25A); also elsewhere on the board
/FPGA + SRAM/IO_B9: U2.L1 (IOB_56); also elsewhere on the board
/FPGA + SRAM/IO_B10: U2.K1 (IOL_23B); also elsewhere on the board
/FPGA + SRAM/IO_T1: U2.D5 (IOT_212); also elsewhere on the board
/FPGA + SRAM/IO_T2: U2.C4 (IOL_4A); also elsewhere on the board
/FPGA + SRAM/IO_T3: U2.D3 (IOL_9B); also elsewhere on the board
/FPGA + SRAM/IO_T4: U2.C3 (IOL_4B); also elsewhere on the board
/FPGA + SRAM/IO_T5: U2.A2 (IOT_222); also elsewhere on the board
/FPGA + SRAM/IO_T6: U2.B1 (IOL_2A); also elsewhere on the board
/FPGA + SRAM/IO_T7: U2.A1 (IOT_225); also elsewhere on the board
/FPGA + SRAM/IO_T8: U2.C2 (IOL_5A); also elsewhere on the board
/FPGA + SRAM/LED_B: U2.J4 (IOB_64); also elsewhere on the board
/FPGA + SRAM/LED_G: U2.L7 (IOB_94); also elsewhere on the board
/FPGA + SRAM/LED_R: U2.J5 (IOB_78); also elsewhere on the board
/FPGA + SRAM/SD_CLK: U2.H2 (IOL_18B); also elsewhere on the board
/FPGA + SRAM/SD_DAT0: U2.J1 (IOL_23A); also elsewhere on the board
/FPGA + SRAM/SD_DAT1: U2.H1 (IOL_18A); also elsewhere on the board
/FPGA + SRAM/SD_DAT2: U2.J3 (IOB_57); also elsewhere on the board
/FPGA + SRAM/SD_DAT3: U2.H3 (IOL_17B); also elsewhere on the board
/FPGA + SRAM/SPI_CNFG_CS_B: JP2.1 (A); also elsewhere on the board
/FPGA + SRAM/USB_H_INT1: U2.B4 (IOT_219); also elsewhere on the board
/FPGA + SRAM/USB_H_INT2: U2.A5 (IOT_207); also elsewhere on the board
/FPGA + SRAM/USB_H_MISO: U2.B3 (IOT_221); also elsewhere on the board
/FPGA + SRAM/USB_H_MOSI: U2.A4 (IOT_211); also elsewhere on the board
/FPGA + SRAM/USB_H_SCK: U2.B2 (IOL_2B); also elsewhere on the board
/FPGA + SRAM/USB_H_SS_B: U2.A3 (IOT_223); also elsewhere on the board
/FPGA + SRAM/USR_BTN1: U2.C7 (IOT_191); also elsewhere on the board
/SD MMC/SD_CMD: U2.J2 (IOL_25B); also elsewhere on the board
CLK: U2.G1 (IOL_14A_GBIN6), Y2.3 (OUT)
GND: C14.2, J4.6, U2.E5 (GND), U2.E6 (GND), U2.E7 (GND), U2.F5 (GND), U2.F6 (GND), U2.F7 (GND), U2.G5 (GND), U2.G6 (GND), U2.G7 (GND), U2.H5 (GND), U3.4 (GND), Y2.2 (GND); also elsewhere on the board
unnamed: R18.1, U3.7 (~HOLD/~RESET/IO_{3})
unnamed: R17.1, U3.3 (~WP/IO_{2})
P1V2: U2.D4 (VCC), U2.D8 (VCC), U2.H4 (VCC), U2.H8 (VCC); also elsewhere on the board
P2V5: U2.C10 (VPP_2V5); also elsewhere on the board
P3V3: C14.1, J4.5, R16.2, R17.2, R18.2, R22.2, R36.2, R40.2, U2.D6 (VCCIO_0), U2.E4 (VCCIO_3), U2.F8 (VCCIO_1), U2.G4 (VCCIO_3), U2.H6 (VCCIO_2), U2.L11 (VCC_SPI), U3.8 (VCC), Y2.4 (Vdd); also elsewhere on the board

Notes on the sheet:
LEFT BANK |---------|
TOP BANK |---------|
SRAM |-----------------------|
I/O |---------|
USB |---------|
BOTTOM BANK |---------|
PROG
FLASH |---------------|
CLOCK |---------|
RIGHT BANK |---------|
PWR + CNFG |---------|
MicroSD |---------|
Organized Quick View

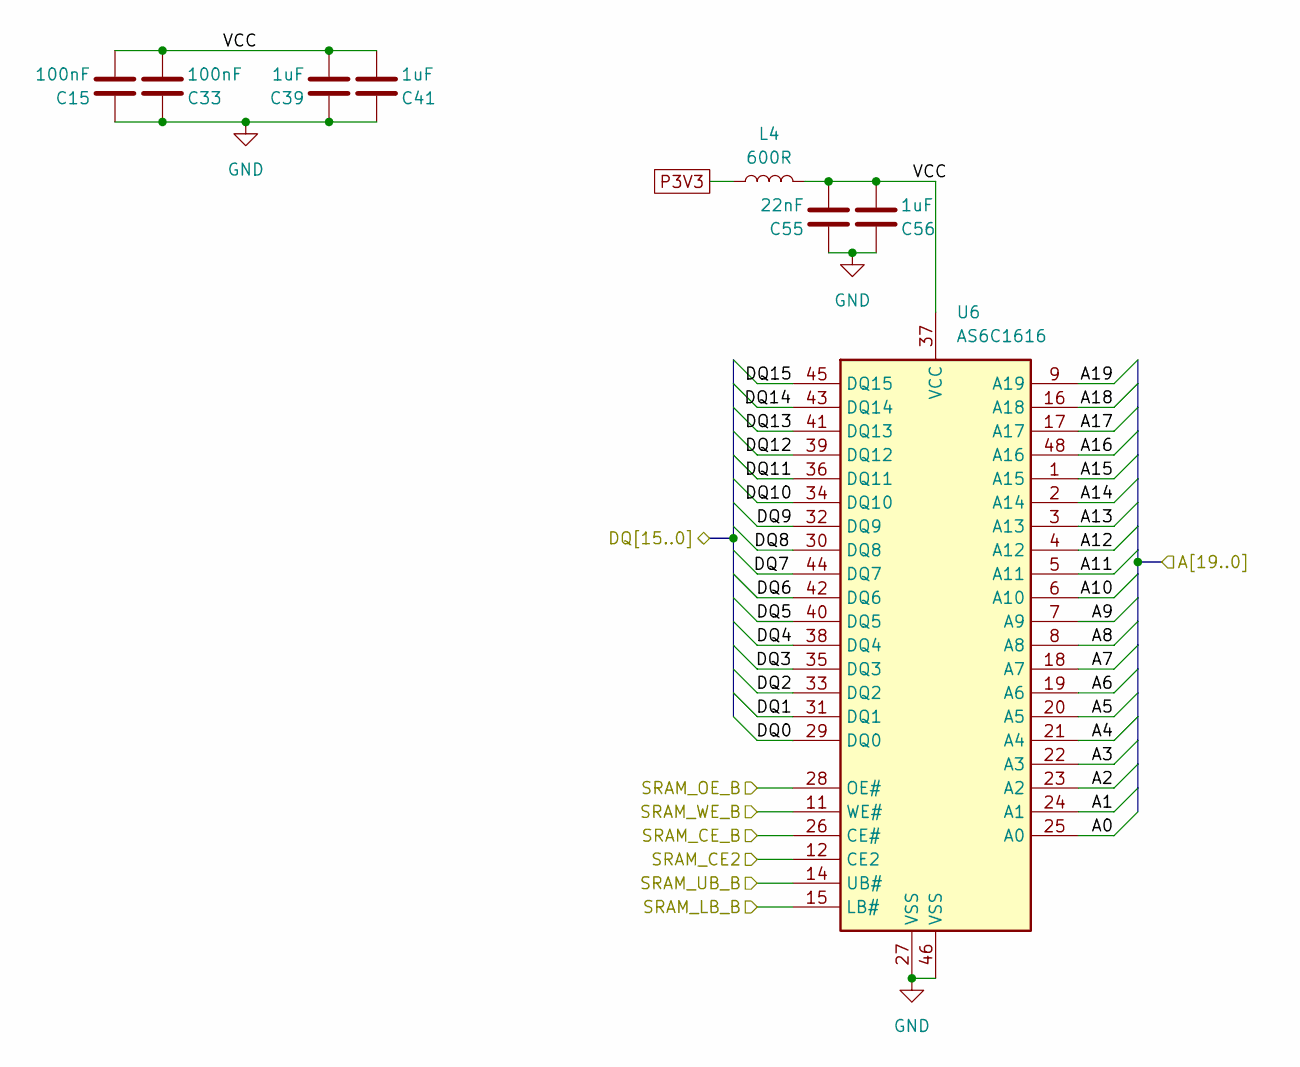
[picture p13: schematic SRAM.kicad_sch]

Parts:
C15, C33: 100nF; C_0603_1608Metric
C39, C41, C56: 1uF; C_0603_1608Metric
C55: 22nF; C_0603_1608Metric
L4: 600R; L_0603_1608Metric
U6: AS6C1616; TSOP-I-48_18.4x12mm_P0.5mm

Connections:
/FPGA + SRAM/FPGA/A0: U6.25 (A0); also elsewhere on the board
/FPGA + SRAM/FPGA/A1: U6.24 (A1); also elsewhere on the board
/FPGA + SRAM/FPGA/A2: U6.23 (A2); also elsewhere on the board
/FPGA + SRAM/FPGA/A3: U6.22 (A3); also elsewhere on the board
/FPGA + SRAM/FPGA/A4: U6.21 (A4); also elsewhere on the board
/FPGA + SRAM/FPGA/A5: U6.20 (A5); also elsewhere on the board
/FPGA + SRAM/FPGA/A6: U6.19 (A6); also elsewhere on the board
/FPGA + SRAM/FPGA/A7: U6.18 (A7); also elsewhere on the board
/FPGA + SRAM/FPGA/A8: U6.8 (A8); also elsewhere on the board
/FPGA + SRAM/FPGA/A9: U6.7 (A9); also elsewhere on the board
/FPGA + SRAM/FPGA/A10: U6.6 (A10); also elsewhere on the board
/FPGA + SRAM/FPGA/A11: U6.5 (A11); also elsewhere on the board
/FPGA + SRAM/FPGA/A12: U6.4 (A12); also elsewhere on the board
/FPGA + SRAM/FPGA/A13: U6.3 (A13); also elsewhere on the board
/FPGA + SRAM/FPGA/A14: U6.2 (A14); also elsewhere on the board
/FPGA + SRAM/FPGA/A15: U6.1 (A15); also elsewhere on the board
/FPGA + SRAM/FPGA/A16: U6.48 (A16); also elsewhere on the board
/FPGA + SRAM/FPGA/A17: U6.17 (A17); also elsewhere on the board
/FPGA + SRAM/FPGA/A18: U6.16 (A18); also elsewhere on the board
/FPGA + SRAM/FPGA/A19: U6.9 (A19); also elsewhere on the board
/FPGA + SRAM/FPGA/DQ0: U6.29 (DQ0); also elsewhere on the board
/FPGA + SRAM/FPGA/DQ1: U6.31 (DQ1); also elsewhere on the board
/FPGA + SRAM/FPGA/DQ2: U6.33 (DQ2); also elsewhere on the board
/FPGA + SRAM/FPGA/DQ3: U6.35 (DQ3); also elsewhere on the board
/FPGA + SRAM/FPGA/DQ4: U6.38 (DQ4); also elsewhere on the board
/FPGA + SRAM/FPGA/DQ5: U6.40 (DQ5); also elsewhere on the board
/FPGA + SRAM/FPGA/DQ6: U6.42 (DQ6); also elsewhere on the board
/FPGA + SRAM/FPGA/DQ7: U6.44 (DQ7); also elsewhere on the board
/FPGA + SRAM/FPGA/DQ8: U6.30 (DQ8); also elsewhere on the board
/FPGA + SRAM/FPGA/DQ9: U6.32 (DQ9); also elsewhere on the board
/FPGA + SRAM/FPGA/DQ10: U6.34 (DQ10); also elsewhere on the board
/FPGA + SRAM/FPGA/DQ11: U6.36 (DQ11); also elsewhere on the board
/FPGA + SRAM/FPGA/DQ12: U6.39 (DQ12); also elsewhere on the board
/FPGA + SRAM/FPGA/DQ13: U6.41 (DQ13); also elsewhere on the board
/FPGA + SRAM/FPGA/DQ14: U6.43 (DQ14); also elsewhere on the board
/FPGA + SRAM/FPGA/DQ15: U6.45 (DQ15); also elsewhere on the board
/FPGA + SRAM/FPGA/SRAM_CE2: U6.12 (CE2); also elsewhere on the board
/FPGA + SRAM/FPGA/SRAM_CE_B: U6.26 (CE#); also elsewhere on the board
/FPGA + SRAM/FPGA/SRAM_LB_B: U6.15 (LB#); also elsewhere on the board
/FPGA + SRAM/FPGA/SRAM_OE_B: U6.28 (OE#); also elsewhere on the board
/FPGA + SRAM/FPGA/SRAM_UB_B: U6.14 (UB#); also elsewhere on the board
/FPGA + SRAM/FPGA/SRAM_WE_B: U6.11 (WE#); also elsewhere on the board
/FPGA + SRAM/SRAM/VCC: C15.1, C33.1, C39.1, C41.1, C55.1, C56.1, L4.2, U6.37 (VCC)
GND: C15.2, C33.2, C39.2, C41.2, C55.2, C56.2, U6.27 (VSS), U6.46 (VSS); also elsewhere on the board
P3V3: L4.1; also elsewhere on the board

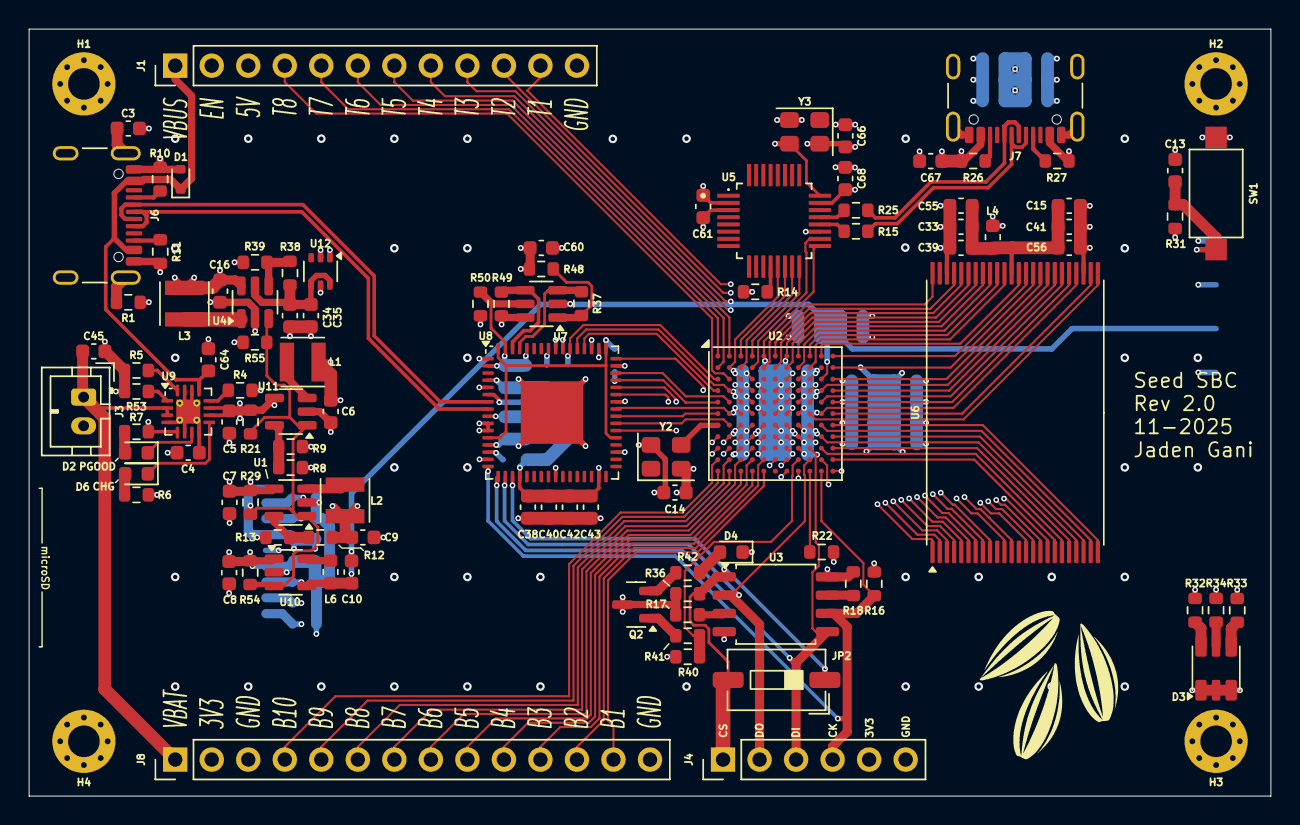
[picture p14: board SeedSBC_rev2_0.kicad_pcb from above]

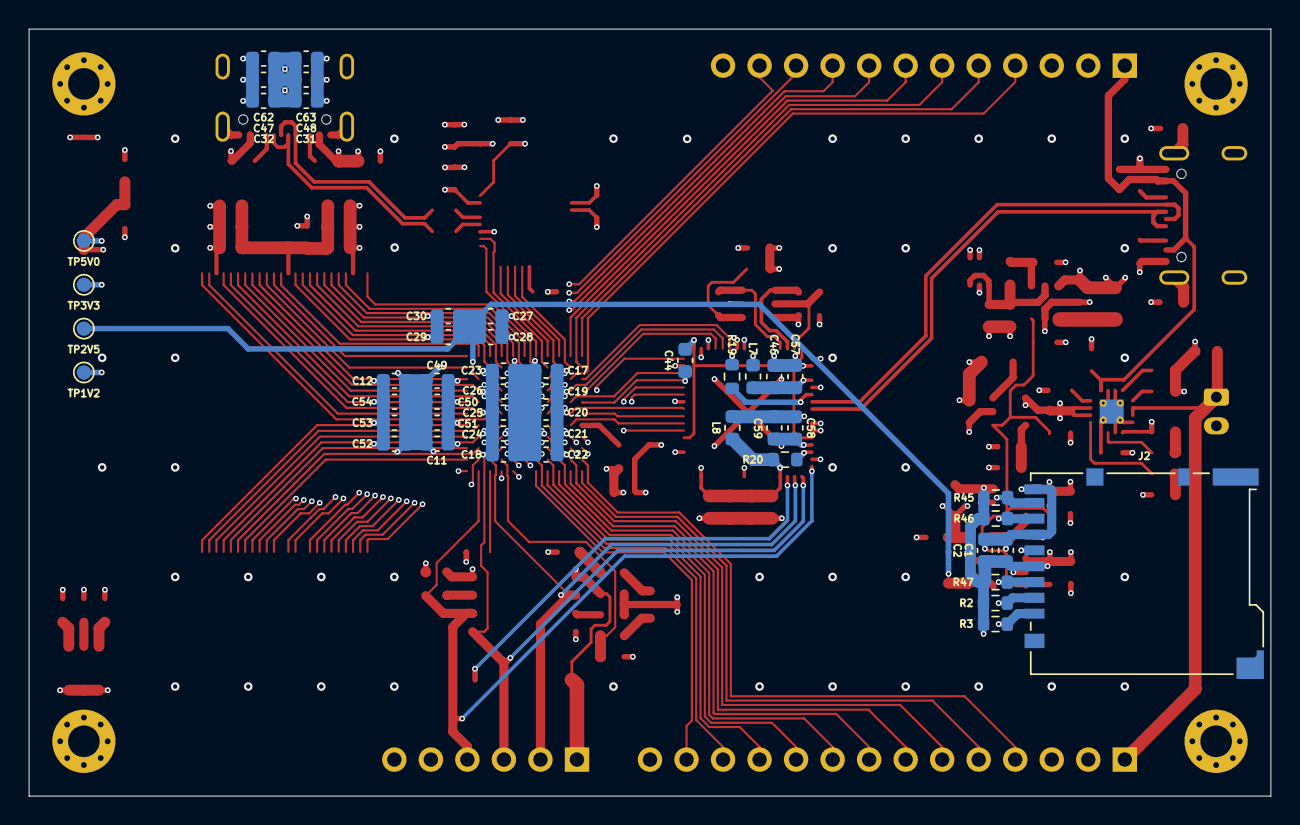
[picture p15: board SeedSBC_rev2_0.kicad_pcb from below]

Board: 8 copper layers, 86.4 x 53.3 mm, 156 parts (49 on the bottom side), 151 nets.

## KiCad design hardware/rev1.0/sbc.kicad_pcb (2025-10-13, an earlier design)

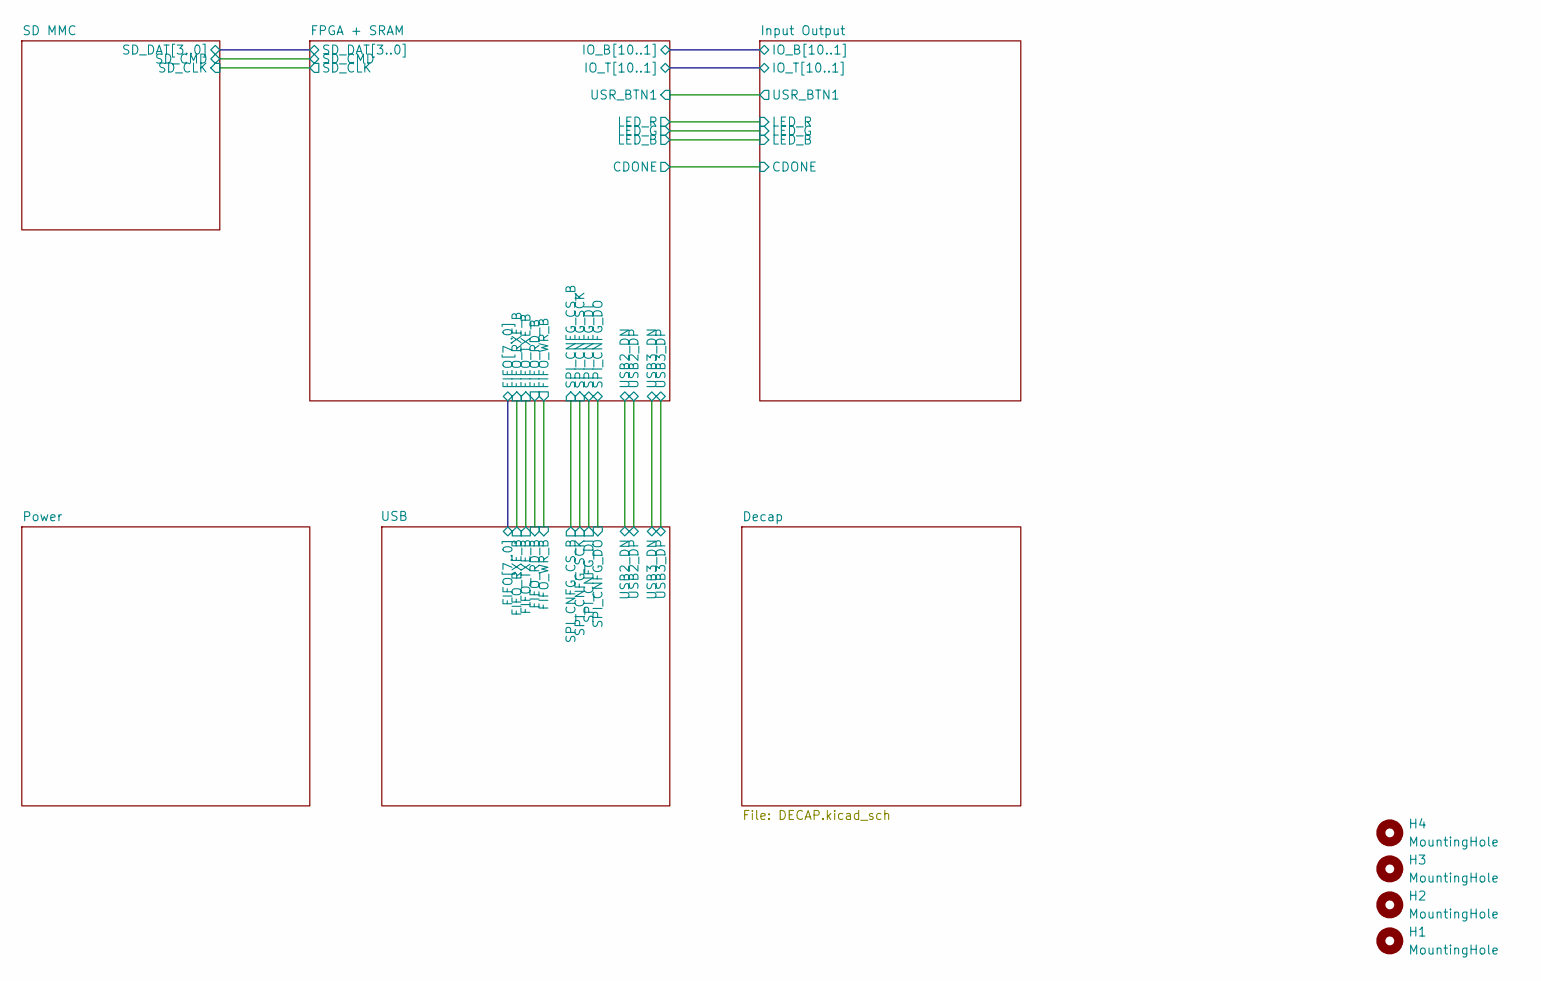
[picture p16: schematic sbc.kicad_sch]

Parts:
H1, H2, H3, H4: MountingHole; MountingHole_2.2mm_M2


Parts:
C3: 100nF; C_0603_1608Metric
C36, C37: 27pF; C_0603_1608Metric
C38, C40, C42, C43, C60: 0.1uF; C_0603_1608Metric
C44: 3.3uF; C_0603_1608Metric
C46, C58: 4.7uF; C_0603_1608Metric
C57, C59: 100n; C_0603_1608Metric
J1, J6, J7: USB_C_Receptacle_USB2.0_14P; USB_C_Receptacle_JAE_DX07S016JA1R1500
L7, L8: 600; L_0603_1608Metric
R1: 1M; R_0603_1608Metric
R10, R11: 5.1k; R_0603_1608Metric
R19: 12k; R_0603_1608Metric
R20, R48, R49, R50: 10k; R_0603_1608Metric
R23, R24, R26, R27: 56k; R_0603_1608Metric
R25, R35, R43, R44: 20R; R_0603_1608Metric
R37: 2.2k; R_0603_1608Metric
U7: 93LCxxBxxOT; SOT-23-6
U8: FT2232HQ; QFN-64-1EP_9x9mm_P0.5mm_EP4.35x4.35mm
U14, U15: NUP2202; SOT-363_SC-70-6
Y1: 12MHz; Crystal_SMD_Abracon_ABM8AIG-4Pin_3.2x2.5mm

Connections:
/FPGA + SRAM/FIFO0: U8.38 (BDBUS0); also elsewhere on the board
/FPGA + SRAM/FIFO1: U8.39 (BDBUS1); also elsewhere on the board
/FPGA + SRAM/FIFO2: U8.40 (BDBUS2); also elsewhere on the board
/FPGA + SRAM/FIFO3: U8.41 (BDBUS3); also elsewhere on the board
/FPGA + SRAM/FIFO4: U8.43 (BDBUS4); also elsewhere on the board
/FPGA + SRAM/FIFO5: U8.44 (BDBUS5); also elsewhere on the board
/FPGA + SRAM/FIFO6: U8.45 (BDBUS6); also elsewhere on the board
/FPGA + SRAM/FIFO7: U8.46 (BDBUS7); also elsewhere on the board
/FPGA + SRAM/FIFO_RD_B: U8.53 (BCBUS2); also elsewhere on the board
/FPGA + SRAM/FIFO_RXF_B: U8.48 (BCBUS0); also elsewhere on the board
/FPGA + SRAM/FIFO_TXE_B: U8.52 (BCBUS1); also elsewhere on the board
/FPGA + SRAM/FIFO_WR_B: U8.54 (BCBUS3); also elsewhere on the board
/FPGA + SRAM/FPGA/SPI_CNFG_DI: U8.17 (ADBUS1); also elsewhere on the board
/FPGA + SRAM/FPGA/SPI_CNFG_DO: U8.18 (ADBUS2); also elsewhere on the board
/FPGA + SRAM/FPGA/SPI_CNFG_SCK: U8.16 (ADBUS0); also elsewhere on the board
/FPGA + SRAM/SPI_CNFG_CS_B: U8.19 (ADBUS3); also elsewhere on the board
/FPGA + SRAM/USB2_DN: R25.2; also elsewhere on the board
/FPGA + SRAM/USB2_DP: R35.2; also elsewhere on the board
/FPGA + SRAM/USB3_DN: R43.2; also elsewhere on the board
/FPGA + SRAM/USB3_DP: R44.2; also elsewhere on the board
/USB/1.8V: C44.1, U8.12 (VCORE), U8.37 (VCORE), U8.49 (VREGOUT), U8.64 (VCORE)
/USB/D1+: J6.A6 (D+), J6.B6 (D+), U8.8 (DP)
/USB/D1-: J6.A7 (D-), J6.B7 (D-), U8.7 (DM)
/USB/D2+: J7.A6 (D+), J7.B6 (D+), R35.1, U15.6
/USB/D2-: J7.A7 (D-), J7.B7 (D-), R25.1, U15.1
/USB/D3+: J1.A6 (D+), J1.B6 (D+), R44.1, U14.6
/USB/D3-: J1.A7 (D-), J1.B7 (D-), R43.1, U14.1
GND: C3.2, C36.2, C37.2, C38.2, C40.2, C42.2, C43.2, C44.2, C46.2, C57.2, C58.2, C59.2, C60.2, J1.A1 (GND), J1.A12 (GND), J1.B1 (GND), J1.B12 (GND), J1.S1 (SHIELD), J6.A1 (GND), J6.A12 (GND), J6.B1 (GND), J6.B12 (GND), J7.A1 (GND), J7.A12 (GND), J7.B1 (GND), J7.B12 (GND), J7.S1 (SHIELD), R1.2, R10.2, R11.2, R19.1, U7.2 (GND), U8.1 (GND), U8.5 (GND), U8.10 (AGND), U8.11 (GND), U8.13 (TEST), U8.15 (GND), U8.25 (GND), U8.35 (GND), U8.47 (GND), U8.51 (GND), U8.65 (GND), U14.2, U15.2; also elsewhere on the board
unnamed: J1.A5 (CC1), R24.1
unnamed: J1.B5 (CC2), R23.1
unnamed: J6.A5 (CC1), R10.1
unnamed: J6.B5 (CC2), R11.1
unnamed: C3.1, J6.S1 (SHIELD), R1.1
unnamed: J7.A5 (CC1), R27.1
unnamed: J7.B5 (CC2), R26.1
unnamed: R49.1, U7.4 (CLK), U8.62 (EECLK)
unnamed: R50.1, U7.5 (CS), U8.63 (EECS)
unnamed: R37.2, U7.3 (DI), U8.61 (EEDATA)
unnamed: R37.1, R48.1, U7.1 (DO)
unnamed: C36.1, U8.2 (OSCI), Y1.1
unnamed: C37.1, U8.3 (OSCO), Y1.2
unnamed: R19.2, U8.6 (REF)
unnamed: C46.1, C57.1, L7.2, U8.4 (VPHY)
unnamed: C58.1, C59.1, L8.2, U8.9 (VPLL)
unnamed: R20.2, U8.14 (~RESET)
P3V3: C38.1, C40.1, C42.1, C43.1, C60.1, L7.1, L8.1, R20.1, R48.2, R49.2, R50.2, U7.6 (VCC), U8.20 (VCCIO), U8.31 (VCCIO), U8.42 (VCCIO), U8.50 (VREGIN), U8.55 (BCBUS4), U8.56 (VCCIO); also elsewhere on the board
USB_VBUS: J6.A4 (VBUS), J6.A9 (VBUS), J6.B4 (VBUS), J6.B9 (VBUS); also elsewhere on the board
USB_VBUS2: J1.A4 (VBUS), J1.A9 (VBUS), J1.B4 (VBUS), J1.B9 (VBUS), J7.A4 (VBUS), J7.A9 (VBUS), J7.B4 (VBUS), J7.B9 (VBUS), R23.2, R24.2, R26.2, R27.2, U14.5, U15.5; also elsewhere on the board

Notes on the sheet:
USB HOST 1 |---------------------------------|
USB MAIN |----------------------------------------------------------------------|
USB HOST 2 |---------------------------------|


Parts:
C11, C17, C19, C20, C21, C22, C27, C28, C31, C32, C49, C50, C51: 100nF; C_0603_1608Metric
C12, C18, C23, C24, C25, C26, C29, C30, C47, C48, C52, C53, C54: 10nF; C_0603_1608Metric
C62, C63: 2.2uF; C_0603_1608Metric

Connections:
GND: C11.2, C12.2, C17.2, C18.2, C19.2, C20.2, C21.2, C22.2, C23.2, C24.2, C25.2, C26.2, C27.2, C28.2, C29.2, C30.2, C31.2, C32.2, C47.2, C48.2, C49.2, C50.2, C51.2, C52.2, C53.2, C54.2, C62.2, C63.2; also elsewhere on the board
P1V2: C17.1, C18.1, C19.1, C20.1, C21.1, C22.1, C23.1, C24.1, C25.1, C26.1; also elsewhere on the board
P2V5: C27.1, C28.1, C29.1, C30.1; also elsewhere on the board
P3V3: C11.1, C12.1, C49.1, C50.1, C51.1, C52.1, C53.1, C54.1; also elsewhere on the board
USB_VBUS2: C31.1, C32.1, C47.1, C48.1, C62.1, C63.1; also elsewhere on the board

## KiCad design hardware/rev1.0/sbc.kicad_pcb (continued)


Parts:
C4, C5, C7, C45: 4.7uF; C_0603_1608Metric
C6, C8, C9, C10, C16: 10uF; C_0603_1608Metric
C34, C35: 22uF; C_0603_1608Metric
C64: 1uF; C_0603_1608Metric
D2, D6: LED; LED_0603_1608Metric
J3: Conn_01x02_Pin; JST_PH_B2B-PH-K_1x02_P2.00mm_Vertical
L1, L2, L3: 2.2uH; L_Neosid_SMS-ME3010
L6: 2.2uH; L_0603_1608Metric
R4: 2.94k; R_0603_1608Metric
R5: 4.32k; R_0603_1608Metric
R6, R7, R21, R29, R53, R54, R55: 10k; R_0603_1608Metric
R8: 450k; R_0603_1608Metric
R9, R12, R13: 100k; R_0603_1608Metric
R38: 560k; R_0603_1608Metric
R39: 62k; R_0603_1608Metric
U1: TLV62568DBV; SOT-23-5
U4: TLV61070ADBV; SOT-23-6
U9: BQ24230RGT; VQFN-16-1EP_3x3mm_P0.5mm_EP1.68x1.68mm_ThermalVias
U10: PAM2305AAB250; TSOT-23-5
U11: TLV62569DBV; SOT-23-5
U12: MIC94093YC6; SOT-363_SC-70-6

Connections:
EN: R21.1, R29.1, R54.2, R55.2, U1.1 (EN), U4.3 (EN), U10.3 (EN), U11.1 (EN); also elsewhere on the board
GND: C4.2, C5.2, C6.2, C7.2, C8.2, C9.2, C10.2, C16.2, C34.2, C35.2, C45.2, C64.2, J3.2, R4.2, R5.2, R9.1, R13.1, R39.1, R53.2, U1.2 (GND), U4.2 (GND), U9.4 (CE), U9.6 (EN1), U9.8 (VSS), U9.14 (TMR), U9.15 (TD), U9.17 (VSS), U10.2 (GND), U11.2 (GND), U12.2 (GND), U12.5 (GND); also elsewhere on the board
unnamed: D2.2 (A), R7.1
unnamed: D2.1 (K), U9.7 (PGOOD)
unnamed: D6.2 (A), R6.1
unnamed: D6.1 (K), U9.9 (CHG)
unnamed: R12.1, R13.2, U1.5 (FB)
unnamed: L2.1, U1.3 (SW)
unnamed: L3.2, U4.1 (SW)
unnamed: R38.1, R39.2, U4.4 (V_{FB})
unnamed: R4.1, U9.12 (ILIM)
unnamed: R5.1, U9.16 (ISET)
unnamed: R53.1, U9.1 (TS)
unnamed: L6.1, U10.5 (SW)
unnamed: R8.1, R9.2, U11.5 (FB)
unnamed: L1.1, U11.3 (SW)
P1V2: C9.1, L2.2, R12.2; also elsewhere on the board
P2V5: C10.1, L6.2, U10.4 (FB); also elsewhere on the board
P3V3: C6.1, L1.2, R8.2; also elsewhere on the board
P5V: C34.1, C35.1, R38.2, U4.5 (V_{OUT}), U12.4 (IN), U12.6 (EN)
USB_VBUS: C64.1, U9.13 (IN); also elsewhere on the board
USB_VBUS2: U12.1 (OUT); also elsewhere on the board
V_BAT: C45.1, J3.1, U9.2 (BAT), U9.3 (BAT); also elsewhere on the board
V_SYS: C4.1, C5.1, C7.1, C8.1, C16.1, L3.1, R6.2, R7.2, R21.2, R29.2, R54.1, R55.1, U1.4 (VIN), U4.6 (V_{IN}), U9.5 (EN2), U9.10 (OUT), U9.11 (OUT), U10.1 (Vin), U11.4 (VIN)

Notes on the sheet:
5V @ 1A
2.5V @ 1A VCCAUX
3.3V @ 2A Max Sys. I/O
R13 (R2 datasheet) = 120k for 1.1V
1.2V @ 1A FPGA VCC
JST


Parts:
C1: 100nF; C_0603_1608Metric
C2: 10uF; C_0603_1608Metric
FB1: 600R; L_0603_1608Metric
J2: Micro_SD_Card; microSD_HC_Hirose_DM3BT-DSF-PEJS
R2, R3, R45, R46, R47: 10k; R_0603_1608Metric

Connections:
/FPGA + SRAM/SD_CLK: J2.5 (CLK); also elsewhere on the board
/FPGA + SRAM/SD_DAT0: J2.7 (DAT0), R46.2; also elsewhere on the board
/FPGA + SRAM/SD_DAT1: J2.8 (DAT1), R45.2; also elsewhere on the board
/FPGA + SRAM/SD_DAT2: J2.1 (DAT2), R3.2; also elsewhere on the board
/FPGA + SRAM/SD_DAT3: J2.2 (DAT3/CD), R2.2; also elsewhere on the board
/SD MMC/3.3V: C1.1, C2.1, FB1.1, J2.4 (VDD)
/SD MMC/SD_CMD: J2.3 (CMD), R47.2; also elsewhere on the board
GND: C1.2, C2.2, J2.6 (VSS), J2.9 (SHIELD); also elsewhere on the board
P3V3: FB1.2, R2.1, R3.1, R45.1, R46.1, R47.1; also elsewhere on the board


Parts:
C13: 4.7uF; C_0603_1608Metric
D3: SMLVN6RGB; LED_ROHM_SMLVN6
D4: LED; LED_0603_1608Metric
J5, J8: Conn_01x14_Pin; PinHeader_1x14_P2.54mm_Vertical
J9: Conn_01x04_Pin; PinHeader_1x04_P1.00mm_Vertical
Q2: BSS84; SOT-23
R31: 10k; R_0603_1608Metric
R32, R33: 20R; R_0603_1608Metric
R34: 60R; R_0603_1608Metric
R41: 100R; R_0603_1608Metric
R42: 270R; R_0603_1608Metric
SW1: SW_Push; SW_SPST_CK_RS282G05A3
TP1V2, TP2V5, TP3V3, TP5V0: TestPoint_Flag; TestPoint_Keystone_5015_Micro_Mini

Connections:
/FPGA + SRAM/CDONE: R41.1; also elsewhere on the board
/FPGA + SRAM/IO_B1: J8.2; also elsewhere on the board
/FPGA + SRAM/IO_B2: J8.3; also elsewhere on the board
/FPGA + SRAM/IO_B3: J8.4; also elsewhere on the board
/FPGA + SRAM/IO_B4: J8.5; also elsewhere on the board
/FPGA + SRAM/IO_B5: J8.6; also elsewhere on the board
/FPGA + SRAM/IO_B6: J8.7; also elsewhere on the board
/FPGA + SRAM/IO_B7: J8.8; also elsewhere on the board
/FPGA + SRAM/IO_B8: J8.9; also elsewhere on the board
/FPGA + SRAM/IO_B9: J8.10; also elsewhere on the board
/FPGA + SRAM/IO_B10: J8.11; also elsewhere on the board
/FPGA + SRAM/IO_T1: J5.2; also elsewhere on the board
/FPGA + SRAM/IO_T2: J5.3; also elsewhere on the board
/FPGA + SRAM/IO_T3: J5.4; also elsewhere on the board
/FPGA + SRAM/IO_T4: J5.5; also elsewhere on the board
/FPGA + SRAM/IO_T5: J5.6; also elsewhere on the board
/FPGA + SRAM/IO_T6: J5.7; also elsewhere on the board
/FPGA + SRAM/IO_T7: J5.8; also elsewhere on the board
/FPGA + SRAM/IO_T8: J5.9; also elsewhere on the board
/FPGA + SRAM/IO_T9: J5.10; also elsewhere on the board
/FPGA + SRAM/IO_T10: J5.11; also elsewhere on the board
/FPGA + SRAM/LED_B: R32.1; also elsewhere on the board
/FPGA + SRAM/LED_G: R33.1; also elsewhere on the board
/FPGA + SRAM/LED_R: R34.1; also elsewhere on the board
/FPGA + SRAM/USR_BTN1: C13.1, R31.1, SW1.2; also elsewhere on the board
EN: J5.13; also elsewhere on the board
EXT_PLL1N: J9.4; also elsewhere on the board
EXT_PLL1P: J9.3; also elsewhere on the board
EXT_PLL2N: J9.2; also elsewhere on the board
EXT_PLL2P: J9.1; also elsewhere on the board
GND: C13.2, D4.1 (K), J5.1, J8.1, J8.12, SW1.1; also elsewhere on the board
unnamed: D3.6 (BK), R32.2
unnamed: D3.4 (GK), R33.2
unnamed: D3.5 (RK), R34.2
unnamed: D4.2 (A), R42.1
unnamed: Q2.1 (G), R41.2
unnamed: Q2.2 (S), R42.2
P1V2: TP1V2.1; also elsewhere on the board
P2V5: TP2V5.1; also elsewhere on the board
P3V3: D3.1 (BA), D3.2 (RA), D3.3 (GA), J8.13, Q2.3 (D), R31.2, TP3V3.1; also elsewhere on the board
USB_VBUS: J5.14; also elsewhere on the board
USB_VBUS2: J5.12, TP5V0.1; also elsewhere on the board
V_BAT: J8.14; also elsewhere on the board

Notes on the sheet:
USER RGB LED |-----------------|
USER BUTTON |-----------------|
GPIO |--------------------------------------|
VBAT 3.3V GND IO 10 IO 9 IO 8 IO 7 IO 6 IO 5 IO 4 IO 3 IO 2 IO 1 GND
RC = 0.1 ms
USB_VBUS EN P5V IO 10 IO 9 IO 8 IO 7 IO 6 IO 5 IO 4 IO 3 IO 2 IO 1 GND
STATUS LED |-----------------|


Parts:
C14: 0.01uF; C_0603_1608Metric
J4: Conn_01x06_Pin; PinHeader_1x06_P2.54mm_Vertical
JP2: Jumper_2_Small_Open; SW_DIP_SPSTx01_Slide_6.7x4.1mm_W6.73mm_P2.54mm_LowProfile_J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
R16, R17, R18, R36: 4.7k; R_0603_1608Metric
R22: 10k; R_0603_1608Metric
R40: 2.2k; R_0603_1608Metric
U2: a; BGA-121_9.0x9.0mm_Layout11x11_P0.8mm_Ball0.4mm_Pad0.35mm_NS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
U3: W25Q32JVSS; SOIC-8_5.3x5.3mm_P1.27mm
Y2: ASE-xxxMHz; Oscillator_SMD_Abracon_ASE-4Pin_3.2x2.5mm

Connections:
/FPGA + SRAM/CDONE: R40.1, U2.K8 (CDONE); also elsewhere on the board
/FPGA + SRAM/FIFO0: U2.H1 (IOL_18A); also elsewhere on the board
/FPGA + SRAM/FIFO1: U2.H2 (IOL_18B); also elsewhere on the board
/FPGA + SRAM/FIFO2: U2.G2 (IOL_14B); also elsewhere on the board
/FPGA + SRAM/FIFO3: U2.F1 (IOL_12A); also elsewhere on the board
/FPGA + SRAM/FIFO4: U2.F2 (IOL_12B); also elsewhere on the board
/FPGA + SRAM/FIFO5: U2.E1 (IOL_8A); also elsewhere on the board
/FPGA + SRAM/FIFO6: U2.E2 (IOL_10A); also elsewhere on the board
/FPGA + SRAM/FIFO7: U2.D1 (IOL_8B); also elsewhere on the board
/FPGA + SRAM/FIFO_RD_B: U2.J5 (IOB_78); also elsewhere on the board
/FPGA + SRAM/FIFO_RXF_B: U2.D2 (IOL_9A); also elsewhere on the board
/FPGA + SRAM/FIFO_TXE_B: U2.H3 (IOL_17B); also elsewhere on the board
/FPGA + SRAM/FIFO_WR_B: U2.J1 (IOL_23A); also elsewhere on the board
/FPGA + SRAM/FPGA/A0: U2.L7 (IOB_94); also elsewhere on the board
/FPGA + SRAM/FPGA/A1: U2.L8 (IOB_103_CBSEL0); also elsewhere on the board
/FPGA + SRAM/FPGA/A2: U2.K11 (IOR_115); also elsewhere on the board
/FPGA + SRAM/FPGA/A3: U2.J10 (IOR_117); also elsewhere on the board
/FPGA + SRAM/FPGA/A4: U2.J11 (IOR_114); also elsewhere on the board
/FPGA + SRAM/FPGA/A5: U2.H10 (IOR_116); also elsewhere on the board
/FPGA + SRAM/FPGA/A6: U2.H11 (IOR_119); also elsewhere on the board
/FPGA + SRAM/FPGA/A7: U2.G10 (IOR_120); also elsewhere on the board
/FPGA + SRAM/FPGA/A8: U2.C11 (IOR_160); also elsewhere on the board
/FPGA + SRAM/FPGA/A9: U2.C9 (IOT_172); also elsewhere on the board
/FPGA + SRAM/FPGA/A10: U2.B11 (IOR_161); also elsewhere on the board
/FPGA + SRAM/FPGA/A11: U2.B9 (IOT_174); also elsewhere on the board
/FPGA + SRAM/FPGA/A12: U2.A11 (IOT_168); also elsewhere on the board
/FPGA + SRAM/FPGA/A13: U2.A10 (IOT_170); also elsewhere on the board
/FPGA + SRAM/FPGA/A14: U2.A9 (IOT_178); also elsewhere on the board
/FPGA + SRAM/FPGA/A15: U2.A8 (IOT_190); also elsewhere on the board
/FPGA + SRAM/FPGA/A16: U2.A5 (IOT_207); also elsewhere on the board
/FPGA + SRAM/FPGA/A17: U2.G11 (IOR_129); also elsewhere on the board
/FPGA + SRAM/FPGA/A18: U2.F10 (IOR_136); also elsewhere on the board
/FPGA + SRAM/FPGA/A19: U2.D10 (IOR_154); also elsewhere on the board
/FPGA + SRAM/FPGA/CRESET_B: R22.1, U2.L9 (~CRESET)
/FPGA + SRAM/FPGA/DQ0: U2.J8 (IOB_91); also elsewhere on the board
/FPGA + SRAM/FPGA/DQ1: U2.H9 (IOB_104_CBSEL1); also elsewhere on the board
/FPGA + SRAM/FPGA/DQ2: U2.G9 (IOR_128); also elsewhere on the board
/FPGA + SRAM/FPGA/DQ3: U2.E8 (IOR_146); also elsewhere on the board
/FPGA + SRAM/FPGA/DQ4: U2.D9 (IOR_147); also elsewhere on the board
/FPGA + SRAM/FPGA/DQ5: U2.C8 (IOT_179); also elsewhere on the board
/FPGA + SRAM/FPGA/DQ6: U2.B8 (IOT_177); also elsewhere on the board
/FPGA + SRAM/FPGA/DQ7: U2.A7 (IOT_192); also elsewhere on the board
/FPGA + SRAM/FPGA/DQ8: U2.H7 (IOB_87); also elsewhere on the board
/FPGA + SRAM/FPGA/DQ9: U2.G8 (IOR_118); also elsewhere on the board
/FPGA + SRAM/FPGA/DQ10: U2.F9 (IOR_137); also elsewhere on the board
/FPGA + SRAM/FPGA/DQ11: U2.E9 (IOR_144); also elsewhere on the board
/FPGA + SRAM/FPGA/DQ12: U2.D7 (IOT_181); also elsewhere on the board
/FPGA + SRAM/FPGA/DQ13: U2.C7 (IOT_191); also elsewhere on the board
/FPGA + SRAM/FPGA/DQ14: U2.B7 (IOT_197_GBIN1); also elsewhere on the board
/FPGA + SRAM/FPGA/DQ15: U2.A6 (IOT_206); also elsewhere on the board
/FPGA + SRAM/FPGA/F: U2.B10 (VPP_FAST)
/FPGA + SRAM/FPGA/SPI_CNFG_CS: J4.1, JP2.2 (B), R36.1, U2.K10 (IOB_108_SS), U3.1 (~CS)
/FPGA + SRAM/FPGA/SPI_CNFG_DI: J4.3, U2.J9 (IOB_106_SDI), U3.5 (DI/IO_{0}); also elsewhere on the board
/FPGA + SRAM/FPGA/SPI_CNFG_DO: J4.4, U2.K9 (IOB_105_SDO), U3.2 (DO/IO_{1}); also elsewhere on the board
/FPGA + SRAM/FPGA/SPI_CNFG_SCK: J4.2, R16.1, U2.L10 (IOB_107_SCK), U3.6 (CLK); also elsewhere on the board
/FPGA + SRAM/FPGA/SRAM_CE2: U2.E11 (IOR_148); also elsewhere on the board
/FPGA + SRAM/FPGA/SRAM_CE_B: U2.K7 (IOB_89); also elsewhere on the board
/FPGA + SRAM/FPGA/SRAM_LB_B: U2.F11 (IOR_140_GBIN3); also elsewhere on the board
/FPGA + SRAM/FPGA/SRAM_OE_B: U2.J7 (IOB_86); also elsewhere on the board
/FPGA + SRAM/FPGA/SRAM_UB_B: U2.E10 (IOR_141_GBIN2); also elsewhere on the board
/FPGA + SRAM/FPGA/SRAM_WE_B: U2.D11 (IOR_152); also elsewhere on the board
/FPGA + SRAM/IO_B1: U2.K6 (IOB_82_GBIN4); also elsewhere on the board
/FPGA + SRAM/IO_B2: U2.K5 (IOB_79); also elsewhere on the board
/FPGA + SRAM/IO_B3: U2.L5 (IOB_81_GBIN5); also elsewhere on the board
/FPGA + SRAM/IO_B4: U2.K4 (IOB_73); also elsewhere on the board
/FPGA + SRAM/IO_B5: U2.L4 (IOB_72); also elsewhere on the board
/FPGA + SRAM/IO_B6: U2.K3 (IOB_63); also elsewhere on the board
/FPGA + SRAM/IO_B7: U2.L3 (IOB_71); also elsewhere on the board
/FPGA + SRAM/IO_B8: U2.K2 (IOL_25A); also elsewhere on the board
/FPGA + SRAM/IO_B9: U2.L2 (IOB_61); also elsewhere on the board
/FPGA + SRAM/IO_B10: U2.L1 (IOB_56); also elsewhere on the board
/FPGA + SRAM/IO_T1: U2.B6 (IOT_198_GBIN0); also elsewhere on the board
/FPGA + SRAM/IO_T2: U2.B5 (IOT_208); also elsewhere on the board
/FPGA + SRAM/IO_T3: U2.A4 (IOT_211); also elsewhere on the board
/FPGA + SRAM/IO_T4: U2.B4 (IOT_219); also elsewhere on the board
/FPGA + SRAM/IO_T5: U2.A3 (IOT_223); also elsewhere on the board
/FPGA + SRAM/IO_T6: U2.B3 (IOT_221); also elsewhere on the board
/FPGA + SRAM/IO_T7: U2.A2 (IOT_222); also elsewhere on the board
/FPGA + SRAM/IO_T8: U2.C2 (IOL_5A); also elsewhere on the board
/FPGA + SRAM/IO_T9: U2.A1 (IOT_225); also elsewhere on the board
/FPGA + SRAM/IO_T10: U2.C1 (IOL_5B); also elsewhere on the board
/FPGA + SRAM/LED_B: U2.K1 (IOL_23B); also elsewhere on the board
/FPGA + SRAM/LED_G: U2.J3 (IOB_57); also elsewhere on the board
/FPGA + SRAM/LED_R: U2.J2 (IOL_25B); also elsewhere on the board
/FPGA + SRAM/SD_CLK: U2.E3 (IOL_10B); also elsewhere on the board
/FPGA + SRAM/SD_DAT0: U2.D3 (IOL_9B); also elsewhere on the board
/FPGA + SRAM/SD_DAT1: U2.D5 (IOT_212); also elsewhere on the board
/FPGA + SRAM/SD_DAT2: U2.G3 (IOL_17A); also elsewhere on the board
/FPGA + SRAM/SD_DAT3: U2.F3 (IOL_13B_GBIN7); also elsewhere on the board
/FPGA + SRAM/SPI_CNFG_CS_B: JP2.1 (A); also elsewhere on the board
/FPGA + SRAM/USB2_DN: U2.B1 (IOL_2A); also elsewhere on the board
/FPGA + SRAM/USB2_DP: U2.B2 (IOL_2B); also elsewhere on the board
/FPGA + SRAM/USB3_DN: U2.C4 (IOL_4A); also elsewhere on the board
/FPGA + SRAM/USB3_DP: U2.C3 (IOL_4B); also elsewhere on the board
/FPGA + SRAM/USR_BTN1: U2.J4 (IOB_64); also elsewhere on the board
/SD MMC/SD_CMD: U2.F4 (IOL_13A); also elsewhere on the board
CLK: U2.G1 (IOL_14A_GBIN6), Y2.3 (OUT)
EXT_PLL1N: U2.L6 (GNDPLL0); also elsewhere on the board
EXT_PLL1P: U2.J6 (VCCPLL0); also elsewhere on the board
EXT_PLL2N: U2.C5 (GNDPLL1); also elsewhere on the board
EXT_PLL2P: U2.C6 (VCCPLL1); also elsewhere on the board
GND: C14.2, J4.6, U2.E5 (GND), U2.E6 (GND), U2.E7 (GND), U2.F5 (GND), U2.F6 (GND), U2.F7 (GND), U2.G5 (GND), U2.G6 (GND), U2.G7 (GND), U2.H5 (GND), U3.4 (GND), Y2.2 (GND); also elsewhere on the board
unnamed: R18.1, U3.7 (~HOLD/~RESET/IO_{3})
unnamed: R17.1, U3.3 (~WP/IO_{2})
P1V2: U2.D4 (VCC), U2.D8 (VCC), U2.H4 (VCC), U2.H8 (VCC); also elsewhere on the board
P2V5: U2.C10 (VPP_2V5); also elsewhere on the board
P3V3: C14.1, J4.5, R16.2, R17.2, R18.2, R22.2, R36.2, R40.2, U2.D6 (VCCIO_0), U2.E4 (VCCIO_3), U2.F8 (VCCIO_1), U2.G4 (VCCIO_3), U2.H6 (VCCIO_2), U2.L11 (VCC_SPI), U3.8 (VCC), Y2.4 (Vdd); also elsewhere on the board

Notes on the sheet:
LEFT BANK |---------|
TOP BANK |---------|
DPair
BOTTOM BANK |---------|
PROG
FLASH |---------------|
CLOCK |---------|
RIGHT BANK |---------|
PWR + CNFG |---------|
More organized version of the above connections for reddit


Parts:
C15, C33: 100nF; C_0603_1608Metric
C39, C41, C56: 1uF; C_0603_1608Metric
C55: 22nF; C_0603_1608Metric
L4: 600R; L_0603_1608Metric
U6: AS6C1616; TSOP-I-48_18.4x12mm_P0.5mm

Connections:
/FPGA + SRAM/FPGA/A0: U6.25 (A0); also elsewhere on the board
/FPGA + SRAM/FPGA/A1: U6.24 (A1); also elsewhere on the board
/FPGA + SRAM/FPGA/A2: U6.23 (A2); also elsewhere on the board
/FPGA + SRAM/FPGA/A3: U6.22 (A3); also elsewhere on the board
/FPGA + SRAM/FPGA/A4: U6.21 (A4); also elsewhere on the board
/FPGA + SRAM/FPGA/A5: U6.20 (A5); also elsewhere on the board
/FPGA + SRAM/FPGA/A6: U6.19 (A6); also elsewhere on the board
/FPGA + SRAM/FPGA/A7: U6.18 (A7); also elsewhere on the board
/FPGA + SRAM/FPGA/A8: U6.8 (A8); also elsewhere on the board
/FPGA + SRAM/FPGA/A9: U6.7 (A9); also elsewhere on the board
/FPGA + SRAM/FPGA/A10: U6.6 (A10); also elsewhere on the board
/FPGA + SRAM/FPGA/A11: U6.5 (A11); also elsewhere on the board
/FPGA + SRAM/FPGA/A12: U6.4 (A12); also elsewhere on the board
/FPGA + SRAM/FPGA/A13: U6.3 (A13); also elsewhere on the board
/FPGA + SRAM/FPGA/A14: U6.2 (A14); also elsewhere on the board
/FPGA + SRAM/FPGA/A15: U6.1 (A15); also elsewhere on the board
/FPGA + SRAM/FPGA/A16: U6.48 (A16); also elsewhere on the board
/FPGA + SRAM/FPGA/A17: U6.17 (A17); also elsewhere on the board
/FPGA + SRAM/FPGA/A18: U6.16 (A18); also elsewhere on the board
/FPGA + SRAM/FPGA/A19: U6.9 (A19); also elsewhere on the board
/FPGA + SRAM/FPGA/DQ0: U6.29 (DQ0); also elsewhere on the board
/FPGA + SRAM/FPGA/DQ1: U6.31 (DQ1); also elsewhere on the board
/FPGA + SRAM/FPGA/DQ2: U6.33 (DQ2); also elsewhere on the board
/FPGA + SRAM/FPGA/DQ3: U6.35 (DQ3); also elsewhere on the board
/FPGA + SRAM/FPGA/DQ4: U6.38 (DQ4); also elsewhere on the board
/FPGA + SRAM/FPGA/DQ5: U6.40 (DQ5); also elsewhere on the board
/FPGA + SRAM/FPGA/DQ6: U6.42 (DQ6); also elsewhere on the board
/FPGA + SRAM/FPGA/DQ7: U6.44 (DQ7); also elsewhere on the board
/FPGA + SRAM/FPGA/DQ8: U6.30 (DQ8); also elsewhere on the board
/FPGA + SRAM/FPGA/DQ9: U6.32 (DQ9); also elsewhere on the board
/FPGA + SRAM/FPGA/DQ10: U6.34 (DQ10); also elsewhere on the board
/FPGA + SRAM/FPGA/DQ11: U6.36 (DQ11); also elsewhere on the board
/FPGA + SRAM/FPGA/DQ12: U6.39 (DQ12); also elsewhere on the board
/FPGA + SRAM/FPGA/DQ13: U6.41 (DQ13); also elsewhere on the board
/FPGA + SRAM/FPGA/DQ14: U6.43 (DQ14); also elsewhere on the board
/FPGA + SRAM/FPGA/DQ15: U6.45 (DQ15); also elsewhere on the board
/FPGA + SRAM/FPGA/SRAM_CE2: U6.12 (CE2); also elsewhere on the board
/FPGA + SRAM/FPGA/SRAM_CE_B: U6.26 (CE#); also elsewhere on the board
/FPGA + SRAM/FPGA/SRAM_LB_B: U6.15 (LB#); also elsewhere on the board
/FPGA + SRAM/FPGA/SRAM_OE_B: U6.28 (OE#); also elsewhere on the board
/FPGA + SRAM/FPGA/SRAM_UB_B: U6.14 (UB#); also elsewhere on the board
/FPGA + SRAM/FPGA/SRAM_WE_B: U6.11 (WE#); also elsewhere on the board
/FPGA + SRAM/SRAM/VCC: C15.1, C33.1, C39.1, C41.1, C55.1, C56.1, L4.2, U6.37 (VCC)
GND: C15.2, C33.2, C39.2, C41.2, C55.2, C56.2, U6.27 (VSS), U6.46 (VSS); also elsewhere on the board
P3V3: L4.1; also elsewhere on the board



Board: 6 copper layers, 76.2 x 50.8 mm, 159 parts (51 on the bottom side), 158 nets.

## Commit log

2025-10-09 setting up repository
    [sbc.kicad_pcb, sbc.kicad_sch]
2025-10-09 added functional unit hierarchy
    [DECAP.kicad_sch, DRAM.kicad_sch, FPGA.kicad_sch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]
2025-10-09 Changed power regulators, filled out DRAM, begin changing FPGA from ECP5 to ICE40
    [DRAM.kicad_sch, FPGA.kicad_sch, POWER.kicad_sch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]
2025-10-09 Saving before changing RAM from DDR3 to Parallel SDR SRAM
    [DECAP.kicad_sch, DRAM.kicad_sch, FPGA+DRAM.kicad_sch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]
2025-10-09 Added more I/O. Changed power regulators
    [DECAP.kicad_sch, FPGA+SRAM.kicad_sch, FPGA.kicad_sch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]
2025-10-09 Power routed. Saving before reworking ICE40 pins to optimize layout
    [DECAP.kicad_sch, FPGA+SRAM.kicad_sch, FPGA.kicad_sch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]
2025-10-10 Finished board. Added BOM
    [FPGA.kicad_sch, IO.kicad_sch, SD_MMC.kicad_sch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]
2025-10-13 End of Version 1.0. Feedback received
    [FPGA.kicad_sch, IO.kicad_sch, POWER.kicad_sch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]
2025-10-13 Started rev1.1. Added revision file hierarchy
    [DECAP.kicad_sch, DRAM.kicad_sch, FPGA+DRAM.kicad_sch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]
2025-10-27 started new through-hole only version
    [DECAP.kicad_sch, FPGA+SRAM.kicad_sch, FPGA.kicad_sch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]
2025-11-22 Finished revision 2.0 modifications and layout. Added ReadMe
    [DECAP.kicad_sch, DRAM.kicad_sch, FPGA+DRAM.kicad_sch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]
2025-11-22 Fixed ReadMe. Fixed PCB Silkscreen
    [SeedSBC_rev2_0-B_Cu.gbr, SeedSBC_rev2_0-B_GND_Cu.gbr, SeedSBC_rev2_0-B_Mask.gbr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]
